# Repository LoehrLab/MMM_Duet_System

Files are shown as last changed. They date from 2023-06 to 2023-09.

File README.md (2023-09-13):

<h1>MMM Duet System</h1>

<h2>Welcome to the MMM Duet System open access build instructions.</h2>

<p>On this site, you will find instructions for how to create your own MMM Duet System. We provide instructions for users who would like to build and use the devices to play musical duets together. We also provide information for researchers and developers who might like to use the MMM Duet System in their research and/or further develop the MMM Duet System. </p>

### [MMM Duet System Hardware](./MMM_Duet_System_Hardware/README.md)
### [MMM Duet System Software](./MMM_Duet_System_Software/README.md)
### [Creating Duets from Commercial Recordings](./Creating_Duets_from_Commercial_Recordings/README.md)

<h3><u>Instructions for users who would like to build and use the devices:</u></h3>
You will need the following software packages.
<ul>
<li>Max 8 or newer </li>
<li>Arduino 1.7 or newer</li>
</ul>

You will also need access to a 3D printer.
<ul><li>
For users who are unfamiliar with 3D printing technology, see https://www.pcmag.com/news/3d-printing-what-you-need-to-know  for an introduction. Note that 3D printing services can be found online or locally. For example, in MMM Duet System’s birthplace, 3D Printing services are available through the public library: https://www.wheatland.sk.ca/services/3D_printing and through a number of 3D printing companies. We used a Prusa i3 MKSS printer with PLA filament for early prototyping and ASA for stronger results in later prototypes. The 3D printing community is very helpful and welcoming if you are having any issues (https://www.reddit.com/r/3Dprinting/, https://forum.prusa3d.com/). Please note that many users’ 3D printing setups show no ventilation, but we strongly advise venting the printer directly outside.</li></ul>

Here are the steps to follow to build your MMM Duet System.
<ol>
<li>Follow the instructions on the MMM Duet System Hardware folder to build your device. </li> 
<li>Follow the instructions on the MMM Duet System Software folder to set up the software. Once this step is complete, you will be able to play duets of various songs that are included in the software package. </li> 
<li>Follow the instructions on the Creating Duets from Commercial Recordings if you’d like to expand the selection of songs to include your personal favourites.</li> 
</ol>

<h3><u>Information for researchers and developers:</u></h3>
<p>To build the MMM Duet System, follow the same instructions as provided for users. Then consult the additional documentation we have provided for developers for further information about how the hardware and software were built and can be modified.</p>
<p>Acknowledgements: Development of the MMM Duet System was supported in part by SHRF, CABHI, and USask Innovation Enterprises.</p>

<p>Please cite this work as follows: Christensen, J., Kauenhofen, S., Loehr, J., Lang, J., Peacock, S., & Nicol, J. (2023). MMM Duet System: New accessible musical technology for people living with dementia. In <i>Proceedings of the 18th International Audio Mostly Conference (Audio Mostly ’23)</i>. Association for Computing Machinery, New York, USA, 7 pages.</p>

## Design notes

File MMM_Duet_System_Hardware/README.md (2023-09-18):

<h1>MMM Duet System Hardware</h1>
<h2><u>Important Files and Sections:</u></h2>

### 1. Shopping list (See section A Below)

### 2. 3D Printing Files (See subfolder Model Files)

These are the files you will need to 3D print the base and handle for each MMM Duet System device.

- Base: 2022_base_model (.f3z, .stl)
  - Component parts:
    - BaseBottom (.3mf, .obj, .stl)
    - BaseTop (.3mf, .obj, .stl)
    - HandleBase (.3mf, .obj, .stl)
- Handle: Crank50mm_solid(.f3z, .stl)
  - Component parts:
    - SolidHandle (.3mf, .obj, .stl)
    - Knob (.3mf, .obj, .stl)

### 3. Arduino Sketch (See subfolder Controller Files)

An Arduino ‘sketch’ is a file that contains the code that runs on an Arduino board (here, the ESP 32). This sketch needs to be loaded onto the Arduino board as detailed in Assembly Step 1.

### 4. Assembly Instructions (See section B Below)

## <u>Overview:</u>

Here are the steps to follow to build the hardware for the MMM Duet System.

1. Purchase items in the Shopping List file.
2. Use a 3D printer to print the components.
3. Put the hardware together by following the steps in the [Assembly Instructions](#b-assembly-instructions).

<h2>A. Shopping List</h2>

This list is for 2 devices

### **Parts**

1. (2) Adafruit Huzzah32 – ESP32 Feather Board (pre-soldered) (https://www.digikey.ca/en/products/detail/adafruit-industries-llc/3591/8119805) This board is slightly more expensive than other ESP32 boards but it was chosen because it comes with a battery charger, JST connection, Wi-Fi and Bluetooth Classic/LE support all on one board. </li>
2. (2) Capacitive Rotary encoders https://www.digikey.ca/en/products/detail/cui-devices/amt103-v/827016
3. (2) 1/4in.(6.35mm)x85mm round metal rods. Note: Rod selection was based partly on availability in our area. For this reason, the holes in the 3D print model are designed to accommodate a 1/4in. (6.35mm) rod. The feel of the rotation can be affected if the gap between the base holes and the rod is too large, so we recommend adjusting the 3D print model to accommodate what is available in your area. The rotary encoders come with a variety of sleeve sizes and can accommodate a broad range of diameters.
4. (2) Protoboards and (4) headers (https://www.amazon.ca/dp/B07CK3RCKS/)
5. (2) Step Up Voltage Module 3.3V to 5V (https://www.amazon.ca/gp/product/B07MTH1R39/)
6. (2) 10K Ohms ±5% and (2) 330K Ohms, ½ Watt, ±5% tolerance, carbon film, resistors
7. (2) 3mm 3.0V-3.4V LED (https://www.amazon.ca/gp/product/B073GRZNRL/)
8. (2)  5 Position MTA 100 Connector Assembly, 22 AWG (https://www.digikey.ca/en/products/detail/te-connectivity-amp-connectors/3-640440-5/698281)
9. (4) Male and (4) Female Spade connectors (optional) (https://www.amazon.ca/gp/product/B08NWXTDN8/)
10. (2) 1000mAh (minimum) Lithium-ion polymer (Lipo) battery (be sure that the polarity of the JST connector matches this https://www.adafruit.com/product/258). There is room for slightly larger batteries, and the model can be modified to accommodate thicker battery packs.
11. (4) M3x8 and (4) M3x12 Hex Screw Bolts (https://www.amazon.ca/gp/product/B0734NVR48/) 
12. (2) M2.6x8 screws (https://www.amazon.ca/Screws-Nickel-Plated-Tapping-Phillips/dp/B0BYNM9522/)
13. (2) M3 Nylon Lock nut (https://www.amazon.ca/gp/product/B07GNH6FVM/)
14. (2) Momentary switches (https://www.amazon.ca/gp/product/B07DS8VSZ1/)

### <b>Supplies</b>

15. 0.6mm Solder (https://www.amazon.ca/gp/product/B071XVPJVX/)  
16. Epoxy (https://www.amazon.ca/Gorilla-Epoxy-85-oz-Clear/dp/B001Z3C3AG/)
17. Filament (depends on printer and desired properties; we used https://us.polymaker.com/products/polylite-asa?variant=39574343221305)  
18. 22AWG Solid Core Wire (https://www.digikey.ca/en/products/detail/adafruit-industries-llc/1311/6198255)
19. Solder Seal Butt Connector (https://www.amazon.ca/NORJIN-Connectors-Waterproof-Electrical-Automotive/dp/B09WQWQQW9/)

### <b>Tools</b>

20. Wire Crimper 
21. Voltage Meter (optional) 
22. Screwdriver that matches bolt/screws 
23. Hot glue gun (optional) 
24. Heat gun 

## B. Assembly Instructions

### **Step 1: Load the Arduino sketch onto the ESP32 board.**

The following instructions explain how to load the Arduino sketch onto the ESP32 Board. We used the Arduino IDE (Integrated Development Environment; see below) due to our familiarity with the software and broad community support.

1. **Install Drivers**
   To load the sketch onto the ESP32 board, you will need to establish a ‘serial connection’ with the board via a ‘COM’ port. To do so, download and install the necessary drivers onto the computer you will use to upload sketch to the board. For a detailed description please visit the manufacturer’s website:
   https://docs.espressif.com/projects/esp-idf/en/latest/esp32/get-started/establish-serial-connection.html

- CP210x Windows/Mac OSX Driver https://www.silabs.com/developers/usb-to-uart-bridge-vcp-drivers

- FTDI Chip VCP Driver https://ftdichip.com/drivers/vcp-drivers/

2. **Set up the Arduino IDE**

- Download and install the Arduino IDE (https://www.arduino.cc/en/software )

- Open the Arduino IDE software, then go to Tools and then Manage Libraries
- Search for and install these libraries:
  - Adafruit BusIO by Adafruit
  - ArduinoOSC by hidekital
- Add the board manager
  - Under File then Preferences, add the following in the text field for Additional Board Manager URLS:
    https://dl.espressif.com/dl/package_esp32_index.json, http://arduino.esp8266.com/stable/package_esp8266com_index.json

3. **‘Flash’ (Arduino’s term for ‘upload’) the sketch onto the board**

- Under Tools, select Board, then ESP32 Arduino, then Adafruit ESP32 Feather
- Plug the USB cable into the board and the computer that you are using to upload the sketch.  
  -Under Tools, select Port, and then select the appropriate COM port. To find the right port: - On PC, open the Device Manager and then expand Ports (COM & LPT). The correct port is listed as Silicon Labs CP210x USB to UART Bridge.

- (Optional) Change the name of the bluetooth controller to avoid confusion with two devices with the same name (e.g., to MMM_Box1).

- Under Sketch, select Upload to upload the sketch to the ESP32 board.

### **Step 2: Wiring**

Below is the wiring schematic. Rather than wire directly to the ESP32 board, we chose to wire to a set of headers soldered to a 30mmx70mm protoboard to prevent damaging the ESP32 board with any soldering mistakes and facilitate reuse of the ESP32 board within the lab (See supplemental information for [soldering instructions](#supplemental-information)).

### Special considerations and recommendations:

- We terminated the ground and positive wires going to the momentary switch with a male spade connector to facilitate connection assembly (optional). Otherwise, the switch can be connected to the protoboard directly.
- The LED is joined to the connecting wires with a solder seal butt connector.
- Connecting the wires to MTA 100 Connector Assembly can be challenging. Rather than acquiring the specialized insertion tool, we used the spanner bit of our screwdriver set.
- We recommend using a volt meter to check conductivity with each connection.

#### **Wiring Diagram**

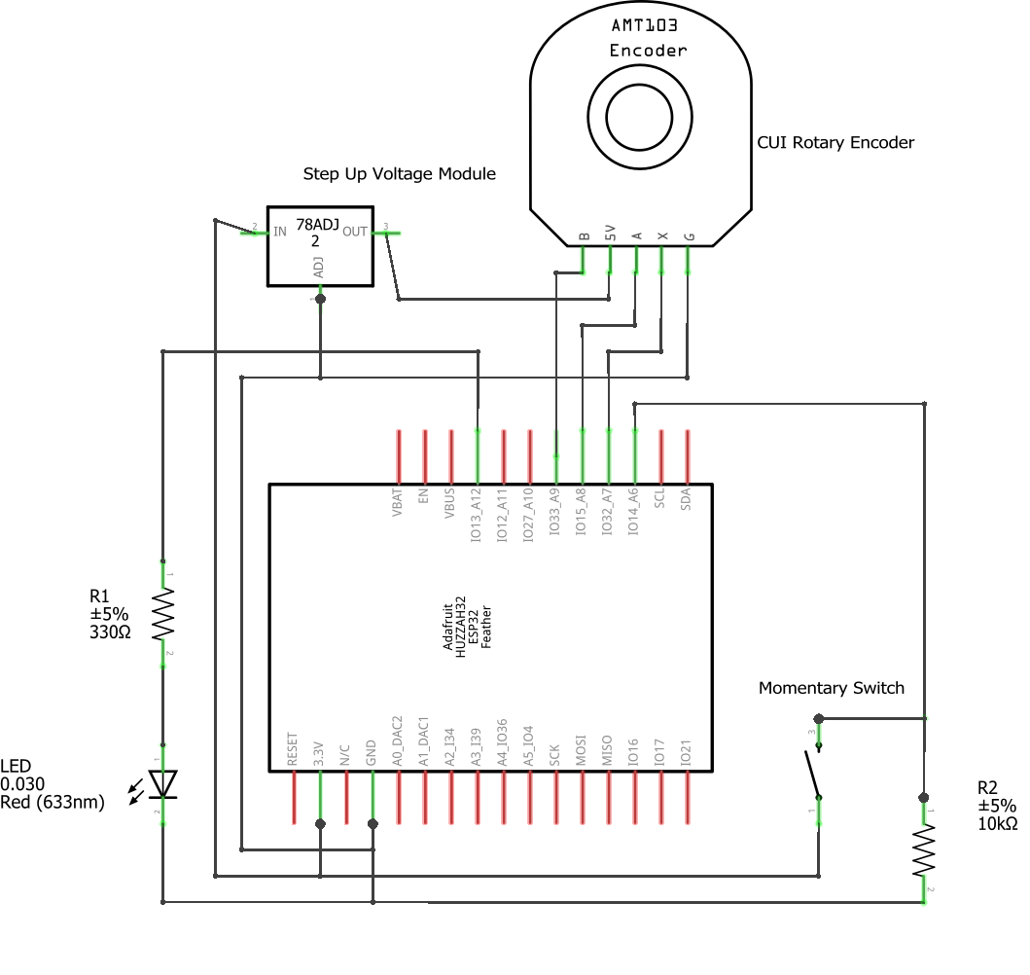
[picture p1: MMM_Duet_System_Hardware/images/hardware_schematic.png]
Wiring Diagram for MMM Duet System.


#### **Breadboard Diagram**

The breadboard diagram below can be used to furhter facilitate conceptualizing of the wiring and testing prior to soldering.
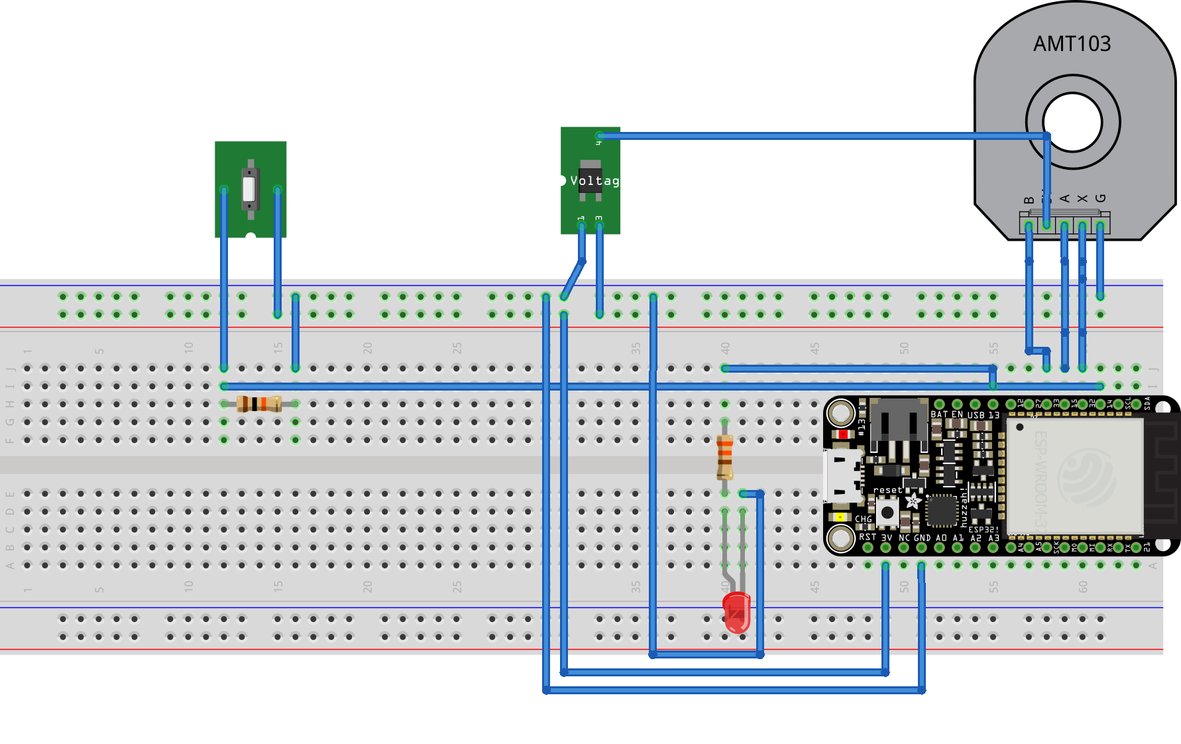
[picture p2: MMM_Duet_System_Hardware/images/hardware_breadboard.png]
Breadboard Diagram for MMM Duet System.


<h3><b>Step 3: Put all the pieces together</b></h3>
<table>
<tr valign="top"><td width="100%">Follow the instructions below to create each MMM Duet System controller.</td></tr>

<tr>
<td width="40%">
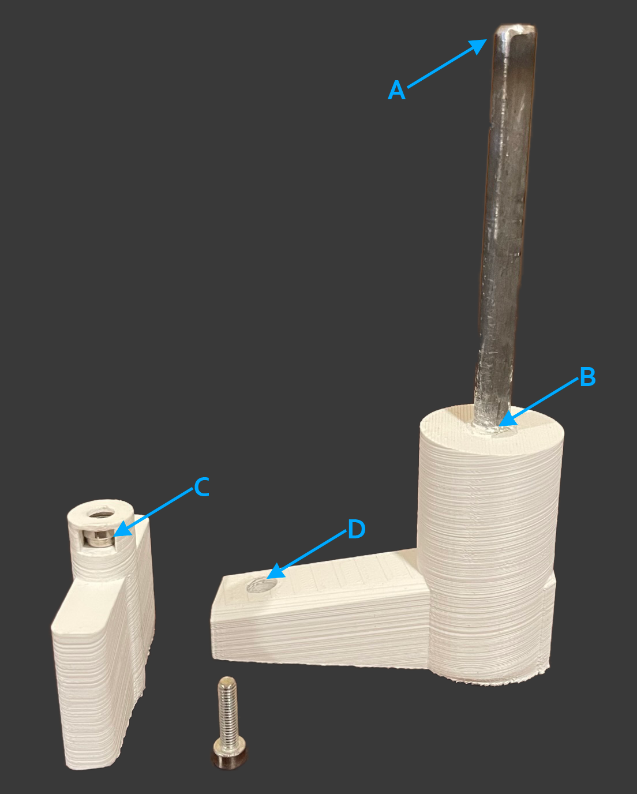
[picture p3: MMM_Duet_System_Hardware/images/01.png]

</td>
<td width="60%">
<ul>
<li>(A) Cut rod to a length of no more than 85mm. Ensure no burs are present to ensure a smooth rotation. </li>
<li>(B) Apply a small amount of epoxy into the hole and quickly set the rod in place. </li>
<li>Let dry before continuing. </li>
<li>(C) Insert the nylon lock nut into the knob such that the hexagon side is towards the circular hole.  </li>
<li>(D) Insert M3x12 screw bolt through handle into knob(C). </li>
</ul>
</td>
</tr>
<tr valign="top">
<td width="40%">
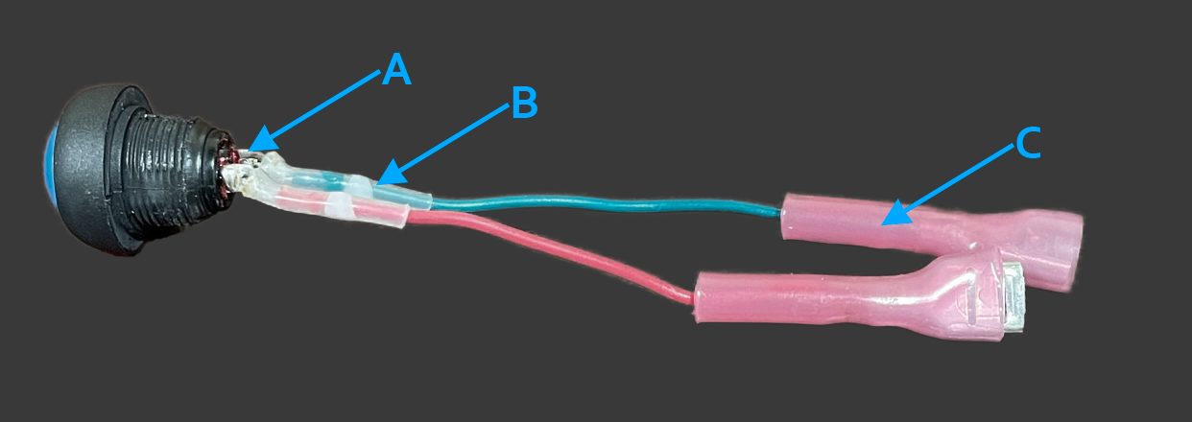
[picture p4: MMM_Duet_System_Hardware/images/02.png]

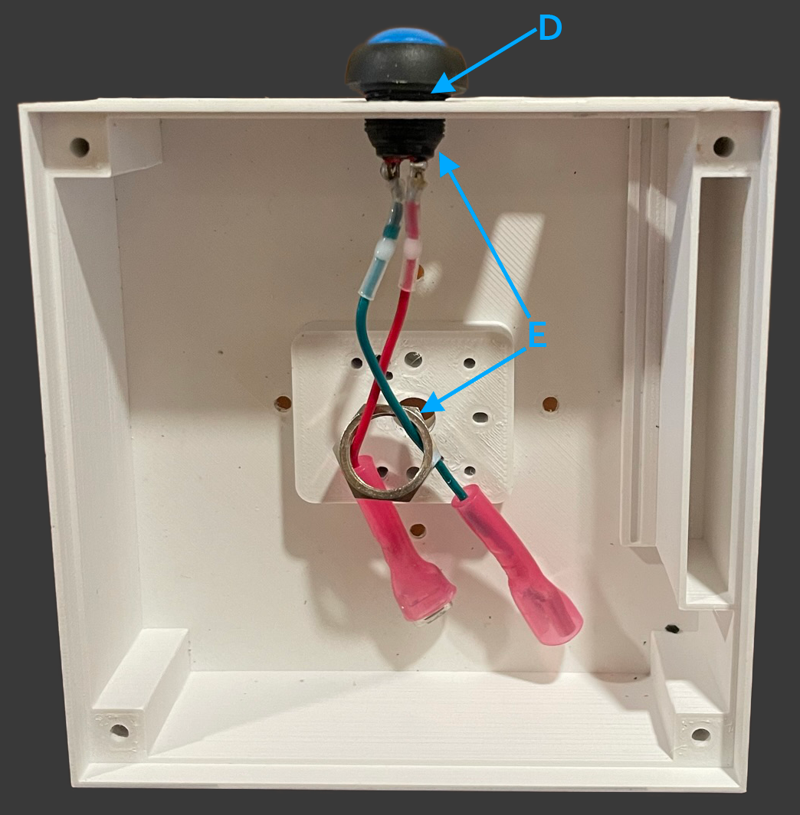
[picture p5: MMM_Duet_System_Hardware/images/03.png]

</td>
<td width="60%">
<ul>
<li>Cut two pieces of wire about 80mm in length; strip both ends.</li>
<li>(A) Hook a wire through each eyelet of the button. </li>
<li>(B) Trim a solder seal butt connector so that the solder is placed where the wire loops onto itself and touches the eyelet.</li> 
<li>Use heat gun to seal butt connector </li>
<li>Repeat for other wire</li>
<li>(C) At the end of the wire, opposite of the button, connect, place a spade connector (female), crimp close and use the heat gun to seal. Optional, you can wire to the protoboard directly, but the wire would need to be cut if any changes would occur in the future. </li>
<li>Repeat for other wire </li>
<li>Remove washer if it is already on the button.</li>
<li>(D) Feed wires through the hole in the base and then through the washer</li>
<li>(E) Tighten washer</li>
</ul>
</td>
</tr>
<tr valign="top">
<td width="40%">
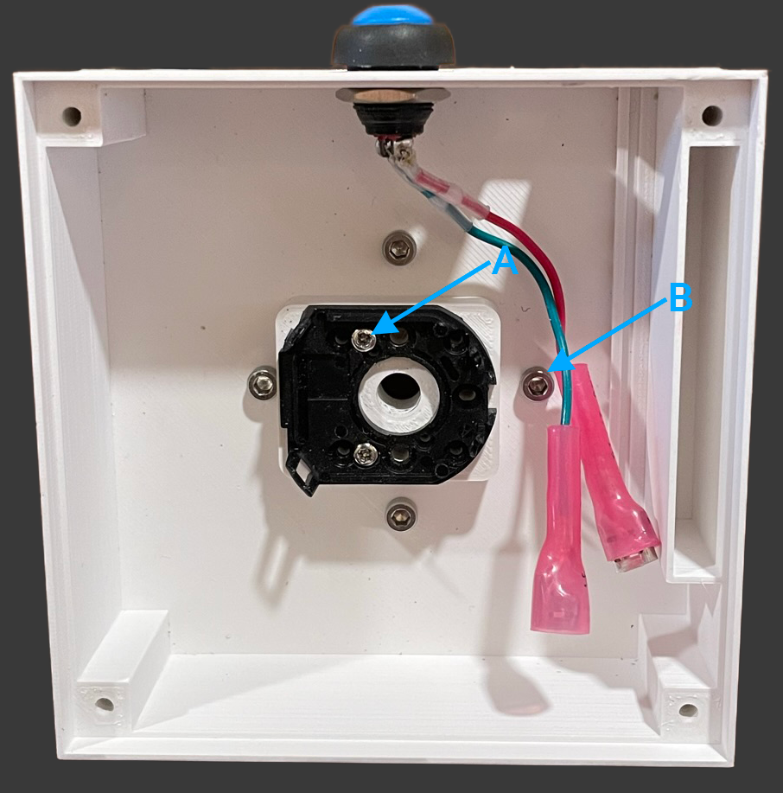
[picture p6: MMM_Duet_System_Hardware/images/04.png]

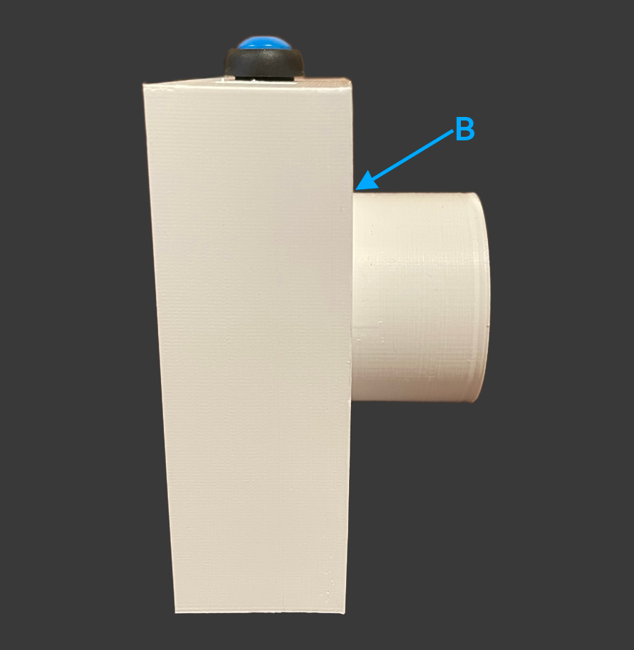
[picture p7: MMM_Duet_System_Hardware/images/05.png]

</td>
<td width="60%">
<ul>
<li>    Align rotary encoder base with the holes in the music box base. </li>
<li>    (A) Insert 2-M2.6x8 screws in two holes that fit snuggly.  </li>
<li>    (B) Align Handle Base (cylinder shape) with the holes in the base. </li> 
<li>    Insert 4-M3x8 screw bolts in the aligned holes </li>
</ul>
</td>
</tr>
<tr valign="top">
<td width="40%">
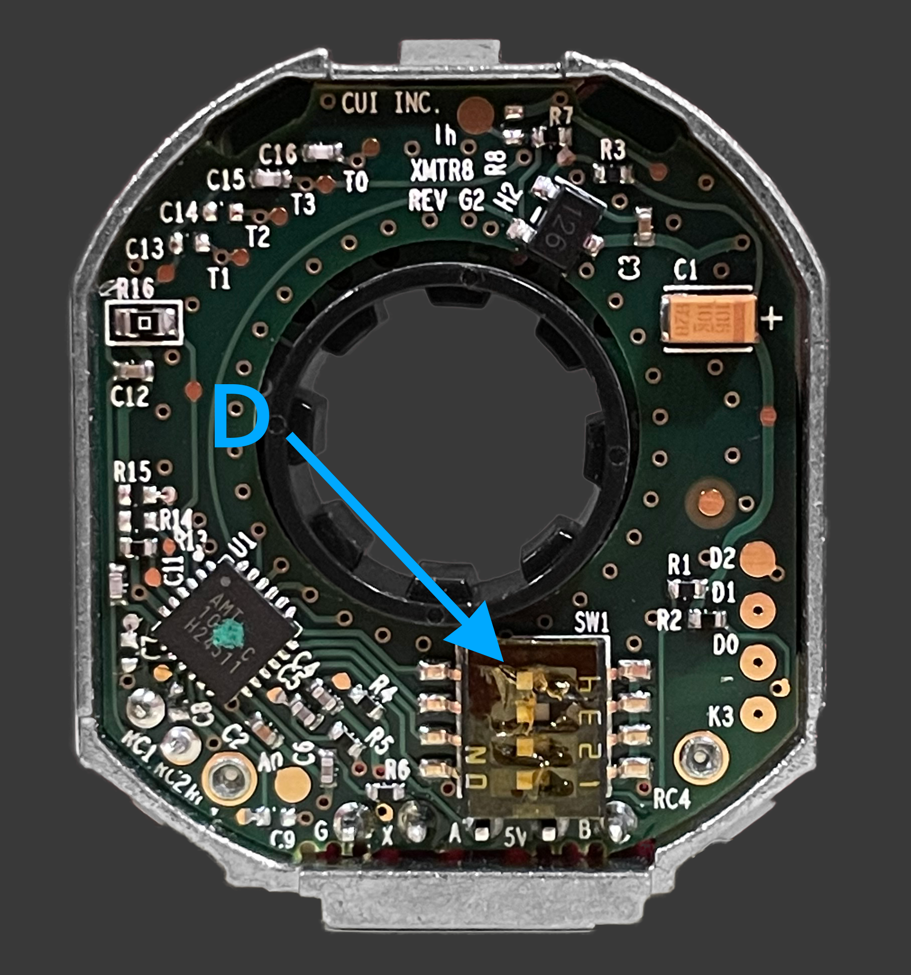
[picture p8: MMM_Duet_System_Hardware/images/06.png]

</td>
<td width="60%">
<ul>
<li>    Adjust the resolution of the encoder to the desired amount. Between 48 and 125 pulses per revolution. See the rotary encoder’s manufacturer’s documentation for more details.  </li>
</ul>
</td>
</tr>
<tr valign="top">
<td width="40%">
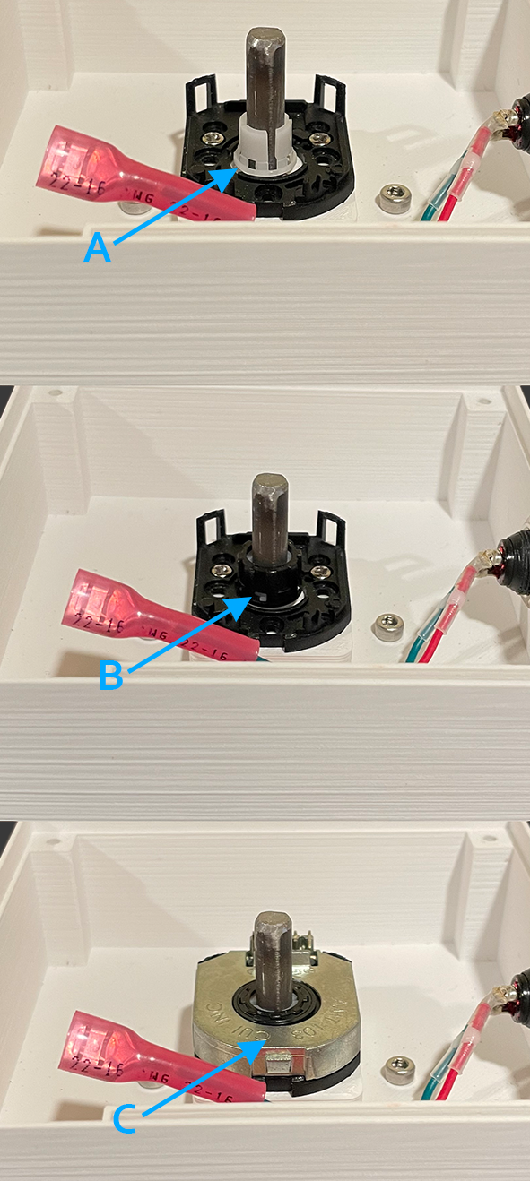
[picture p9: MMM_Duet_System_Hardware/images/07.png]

</td>
<td width="60%">
<ul>
<li>    Push handle as far as possible through the hole at the top of the base. </li>
<li>    (A) Place the coloured sleeve that matches the diameter of the rod approximately 1 mm from the printed model. See https://www.cuidevices.com/product/resource/amt10.pdf for the sleeve sizing guide. </li>
<li>    (B) Place black shaft adapter over the white sleeve. The rod should be difficult to remove at this point. If the sleeve needs to be adjusted remove the shaft adapter and then adjust the sleeve.  </li> 
<li>    (C) Gently clip the encoder into place. The black tabs of the encoder base break easily. </li>
</ul>
</td>
</tr>
<tr valign="top">
<td width="40%">
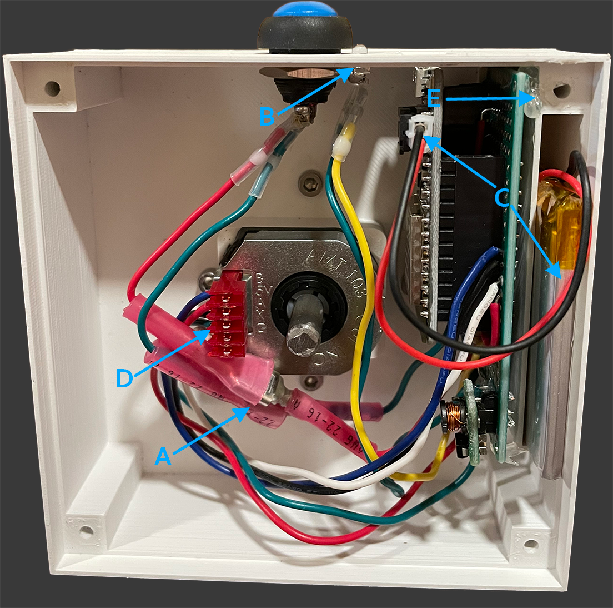
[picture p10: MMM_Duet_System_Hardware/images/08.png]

</td>
<td width="60%">
<ul>
<li>    (A) Connect button spade connectors of the protoboard to those of the ESP32. </li>
<li>    (B) Push LED light snuggly into hole </li>
<li>    (C) Connect battery pack to the ESP32 and place battery in pocket. </li> 
<li>    Seat ESP32 in the headers of the protoboard. </li>
<li>    Place protoboard in slot </li>
<li>    (D) Connect the 5 Position MTA 100 connector to the rotary encoder. </li>
<li>   (Optional) (E) Use hot glue gun to improve stability of protoboard and ease of installation. </li>
</ul>
</td>
</tr>
<tr valign="top">
<td width="40%">
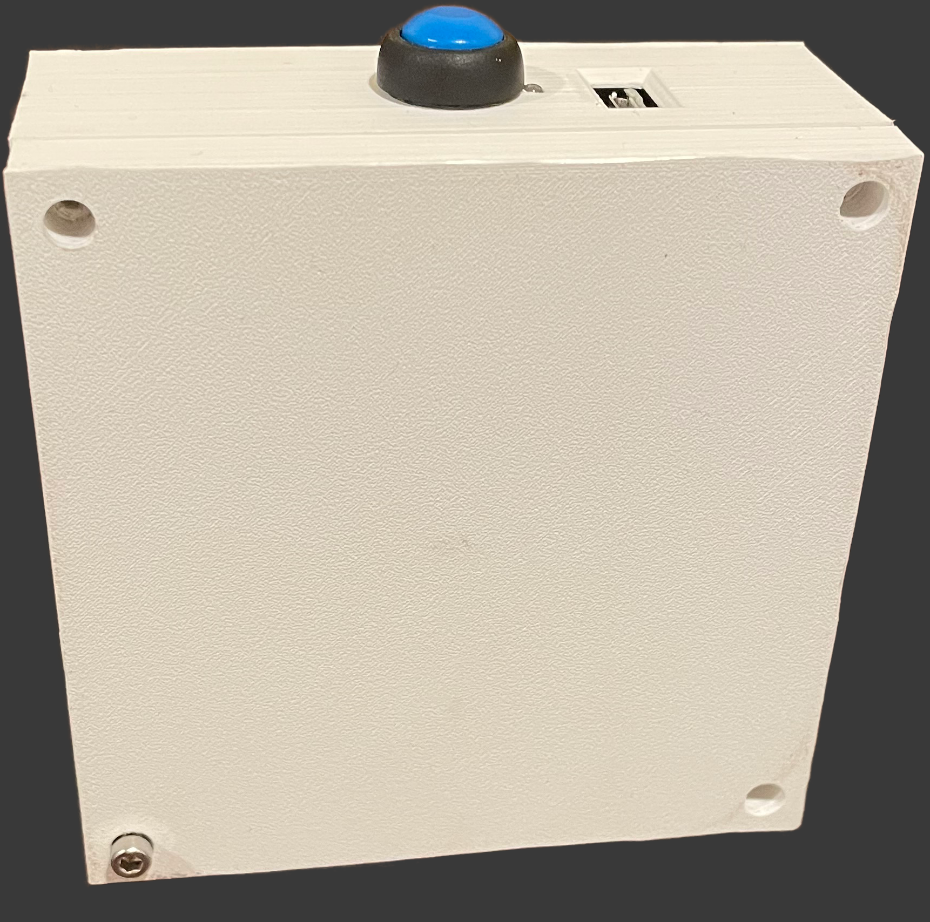
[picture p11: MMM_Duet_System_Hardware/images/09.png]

</td>
<td width="60%">
<ul>
<li>Add bottom panel and screw into place with M3x12 bolt screws. </li>
</ul>
</td>
</tr>
<tr valign="top">
<td width="40%">
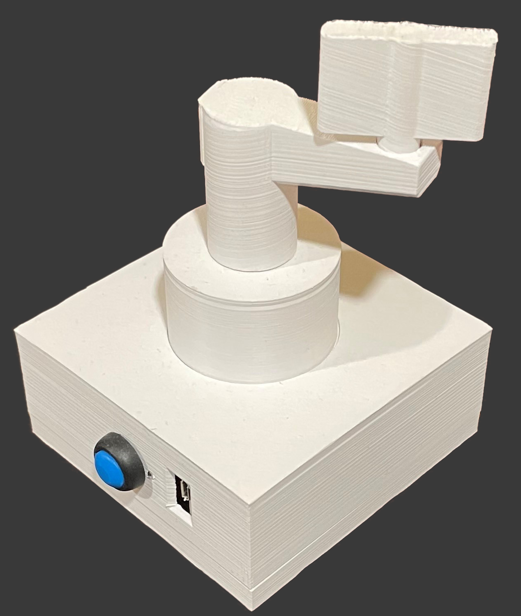
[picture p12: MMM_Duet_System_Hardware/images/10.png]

</td>
<td width="60%">
<ul>
<li>    Enjoy! </li>
</ul>
</td>
</tr>
</table>

## Supplemental Information
<table>
<table><tr valign="top"><h3><b>Soldering instructions</b></h3></tr>
The following Instructions are for putting together ONE device. The images often show two devices being assembled; this is to help aid in understanding by showing multiple angles in one image. Note that there may be other, more efficient ways to assemble the devices; we learned by doing and these are the steps we currently follow to put the devices together.

<tr>
<td width="30%">

1. Place the ESP32 board into a row of headers.
2. Remove excess pins by placing a pliers one pin past the pins you need to keep. In the next step when you snap it, the headers tend to break where it is not solid, which will now be just after the last pin you need.
3. Snap the header.
4. Break off any rough edges.
5. Repeat for the other row of headers.

<td colspan="2">

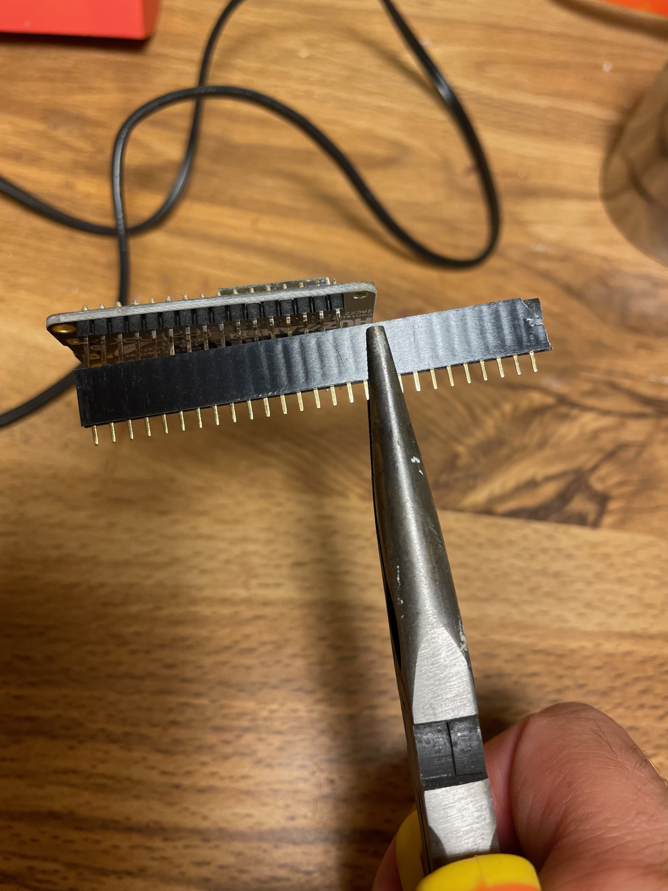
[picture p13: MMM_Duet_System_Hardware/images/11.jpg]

</td>

</tr>
<tr>
<td width="30%">

6. Use the ES32 board to hold the headers in place. Leave one column of holes in the perf board to accommodate wires going to the encoder.
7. Solder at a couple of points to hold the headers in place.
8. Remove the ESP32 board.
9. Solder remaining pins.

<td width="35%">

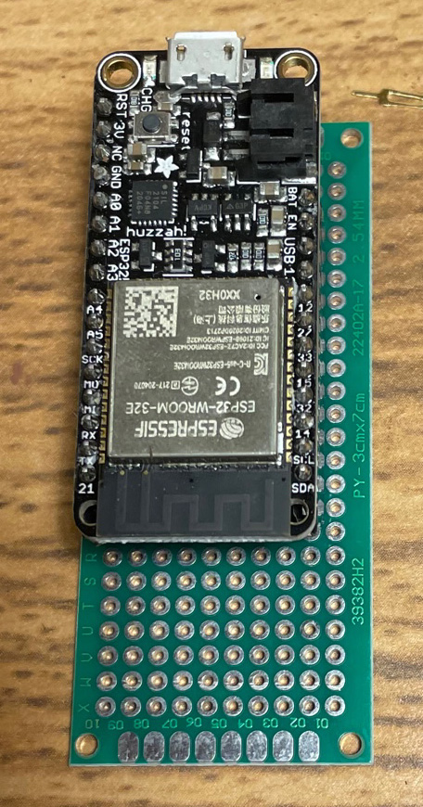
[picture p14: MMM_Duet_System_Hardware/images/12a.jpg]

</td>
<td width="35%">

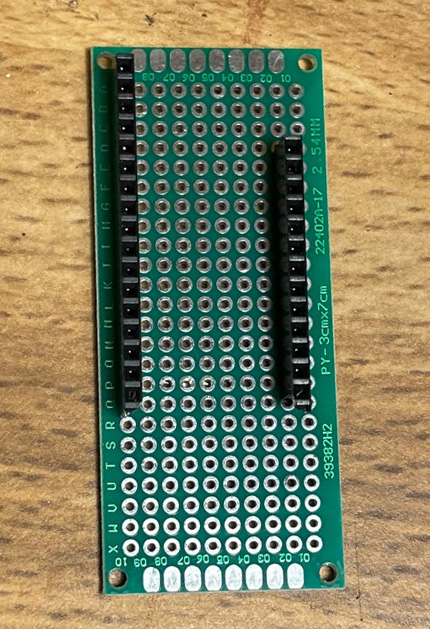
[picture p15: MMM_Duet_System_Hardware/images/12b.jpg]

</td>
</tr>
<tr>
<td width="30%">

10. With the headers securely in place:
11. Cut wires slightly shorter in length than the perf board.
12. Strip the wire ends approximately 1 cm.

<td colspan="2">

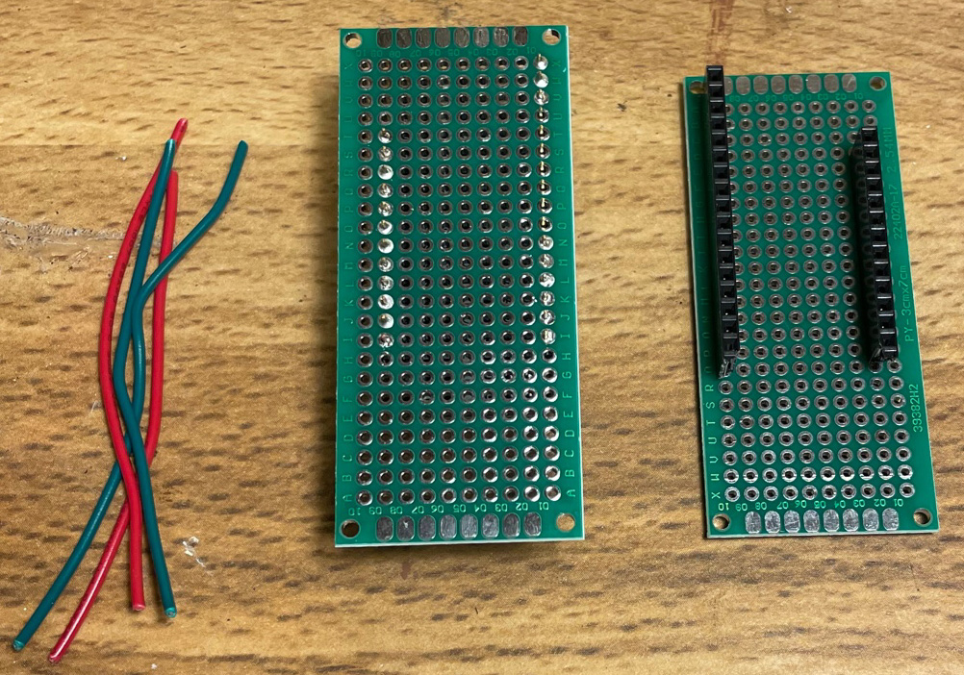
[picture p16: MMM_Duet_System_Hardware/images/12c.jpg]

</td>

</tr>
<tr>
<td width="30%">

13.	Imagine 3 strips (encircled in different colours at the bottom of the board in the image on the right). One for the 3.3V, one for the ground, and one for the 5V. This corresponds to the positions in the Step-up Voltage Module . If the modules do not come with reference material, testing must be done to determine which pin is the higher voltage. In our case the light red corresponds to the 3.3V, the ground is green, and the 5V is dark red. Insert the wire next to the pin of the 3.3V of the ESP32 board (I.e., where the bright red dot is).
14.	Insert the other end on the corresponding strip (I.e., where the bright red dot is on the bottom strip).
15.	Solder the wire at the strip end in place.
16.	Bend the wire over to touch the pin of the header (see image on right). 
17.	Solder the wire to  the pin.
<td width="35%">
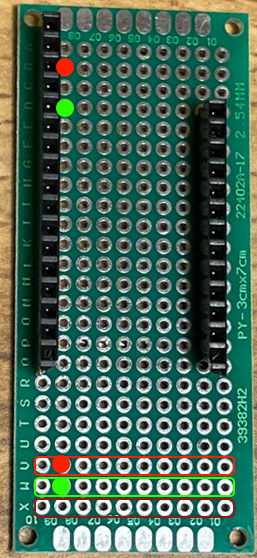
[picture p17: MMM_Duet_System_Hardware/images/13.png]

</td>
<td width="35%">
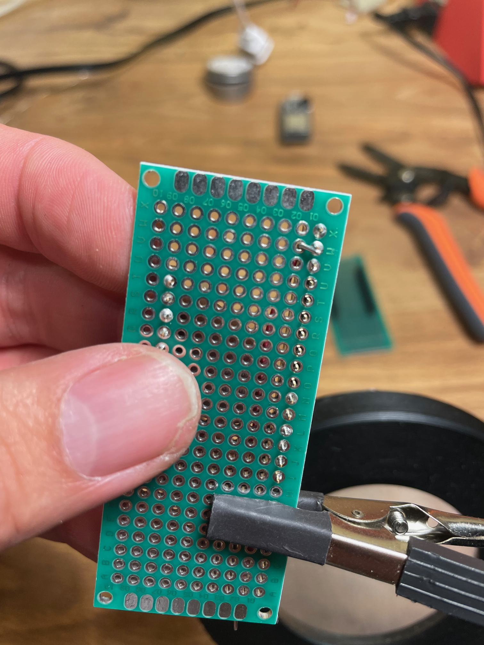
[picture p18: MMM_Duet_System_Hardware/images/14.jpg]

</td>
</tr>
<tr>
<td width="30%">

18.  It is helpful to test the connectivity after each connection in order to avoid having to search for problems later. To do so it is helpful to have some jumper wires inserted into the header as shown on the right. 
<td colspan="2">
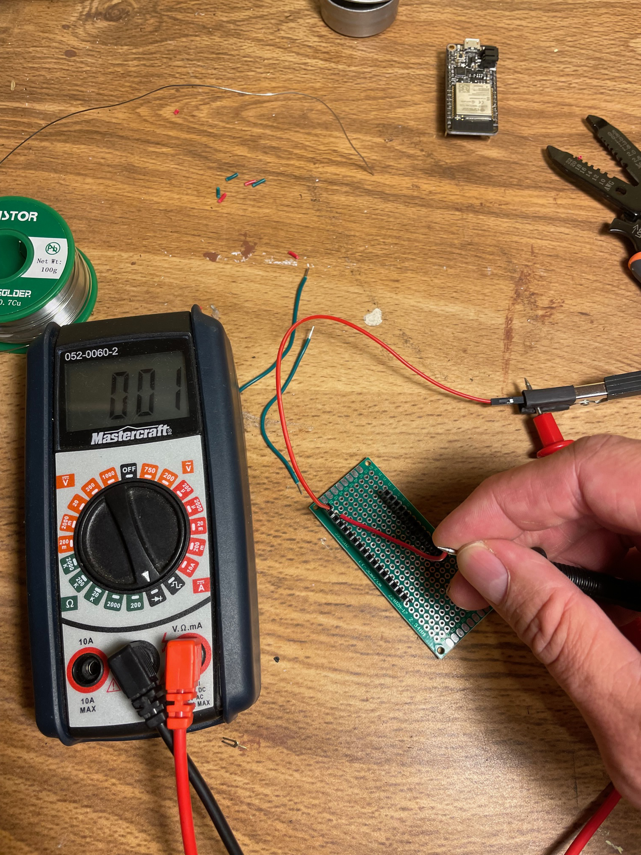
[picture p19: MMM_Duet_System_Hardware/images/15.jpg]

</td>
</tr>

<tr>
<td width="30%">

19.	Cut and strip one end of each of 3 wires about 6 in. (15 cm) in length.
20.	Cut and strip both ends of a wire about 2 in. (5 cm) in length.
21.	Solder the wires, as done previously, adjacent to the A6, A7, A8, & A9 pins. The shorter wire should be adjacent to the A6 pin.
22.	Solder a connection between the wires and their adjacent pins.
23.	Solder a male/male header to connect the Step-up Voltage Module.
<td colspan="2">
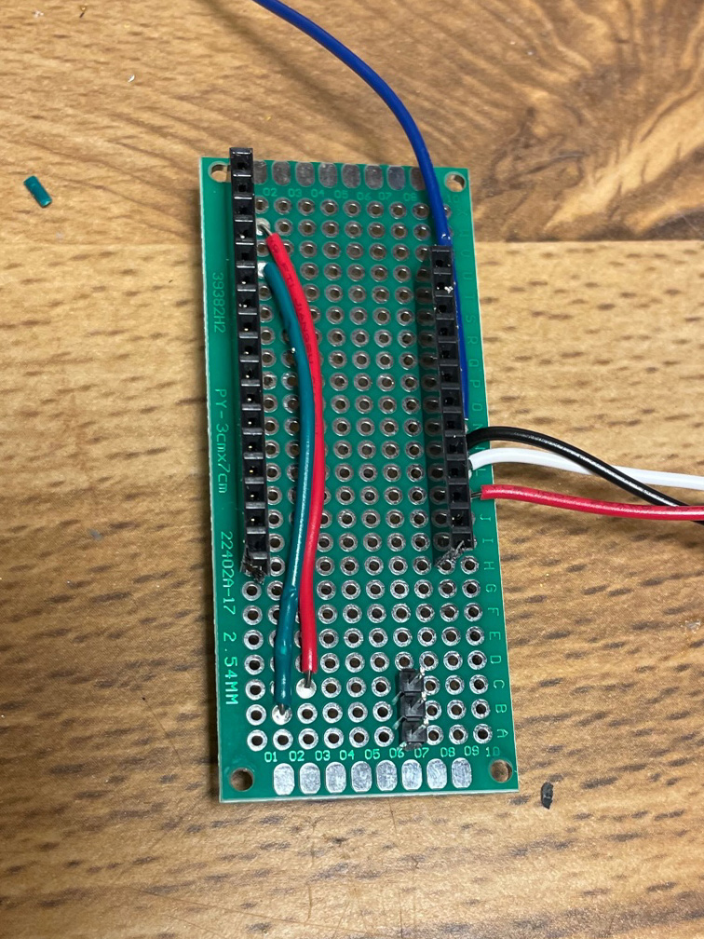
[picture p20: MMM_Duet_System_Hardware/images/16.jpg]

</td>
</tr>

<tr>
<td width="30%">

24.	Place the Step-up Voltage regulator on the header pins. Test to confirm that it is positioned correctly. For the regulators we purchased, the v0 pin was the 5V and the v1 pin was the 3.3V. 
25.	Solder the Step-up Voltage regulator in place.
26.	Solder the wire from the A6 pin somewhere in the space between the rows of headers.
<td colspan="2">
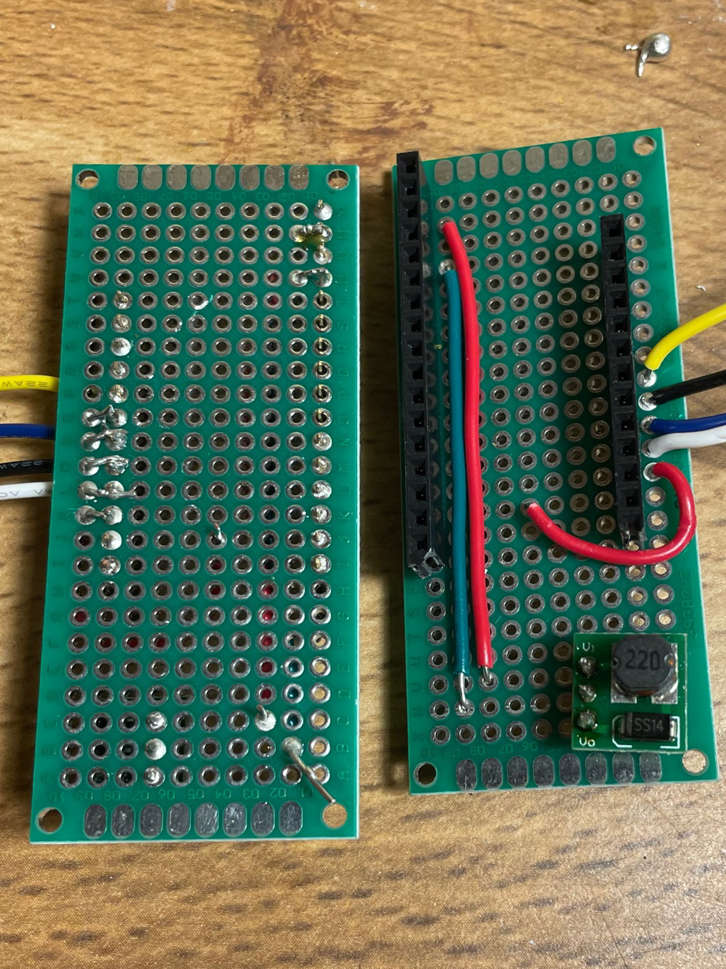
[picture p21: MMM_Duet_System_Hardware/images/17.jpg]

</td>
</tr>

<tr>
<td width="30%">

27.	Solder a 10K Ohm resistor between the wire from the A6 pin to the ground strip shown in step 13.
28.	Solder a connection between the A6 wire and the resistor.
<td colspan="2">
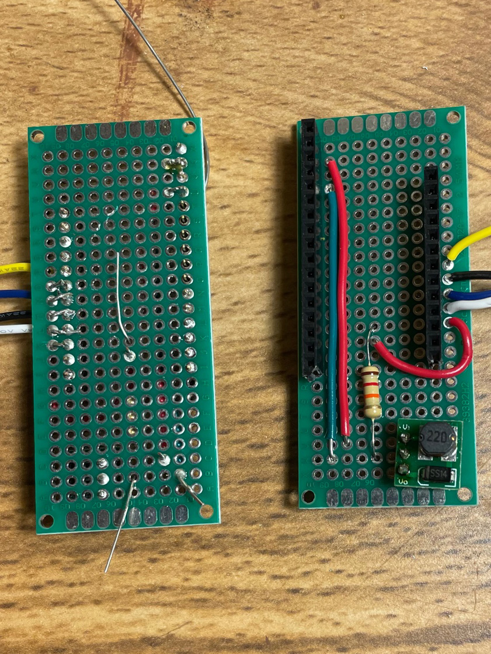
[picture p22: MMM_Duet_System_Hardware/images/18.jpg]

</td>
</tr>

<tr>
<td width="30%">

29.	Cut and strip 2 wires about 4 in. (10 cm) in length (the wires for 2 devices are shown).
30.	Crimp the male spade connectors on the wires.
31.	Use a heat gun to shrink.
32.	Test the connection. If it doesn’t have a satisfactory connection, you can apply a little solder to improve the connection.
<td colspan="2">
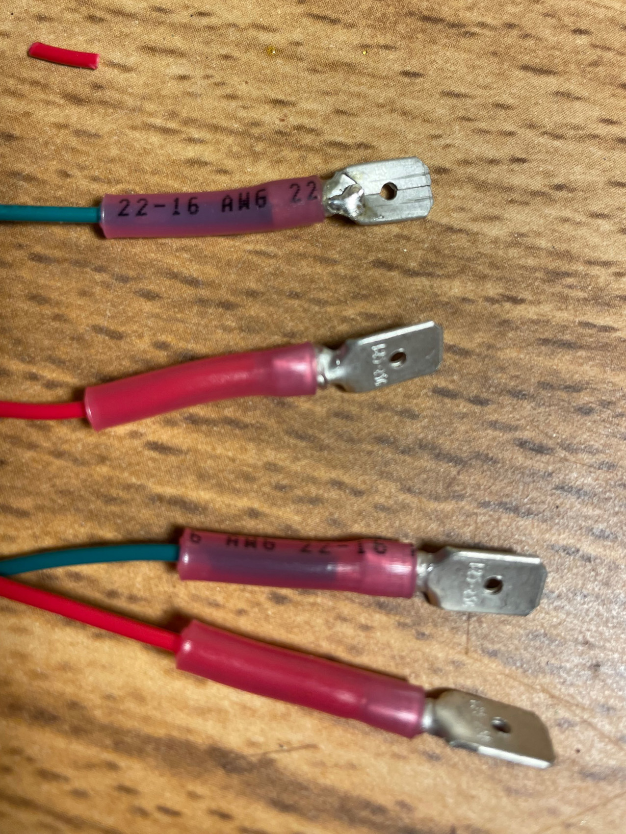
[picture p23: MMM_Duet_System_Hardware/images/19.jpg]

</td>
</tr>

<tr>
<td width="30%">

33.	Solder one wire opposite the 10K Ohm resistor and solder a connection between the two.
34.	Solder one wire to the 3.3V strip shown in Step 13. 
<td colspan="2">
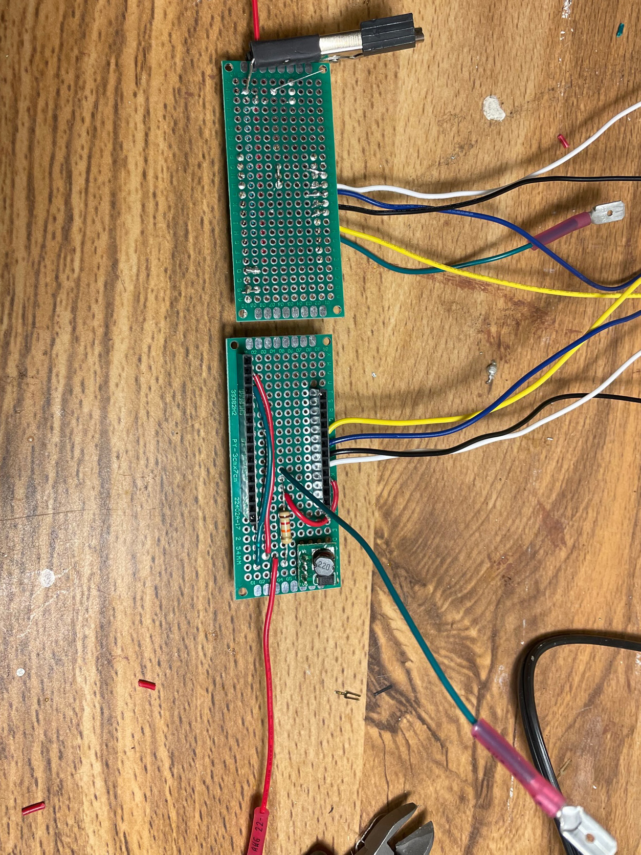
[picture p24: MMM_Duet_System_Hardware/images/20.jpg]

</td>
</tr>

<tr>
<td width="30%">

35.	Insert the 330 Ohm resistor adjacent to the A12 pin. 
36.	Insert the other end into a space between the two rows of headers.
37.	Solder in place.
38.	Solder a connection between the resistor and the A12 pin.
<td colspan="2">

</td>
</tr>

<tr>
<td width="30%">

39.	Cut and strip two wires approximately 4 in. (10 cm) in length.
40.	Cut two solder seal butt connectors so the solder in the middle can seal the connection between the stripped wire and the LED.
41.	Trim the LED of any excess but be sure to keep the longer lead (leg) longer. The longer lead should connect to the resistor and the shorter lead should go to the ground.
42.	Use a heat gun to melt solder and heat wrap.
43.	(Optional) Tape the two wires together just below the LED with electrical tape for strength.

<td width="35%">

</td>
<td width="35%">

</td>
</tr>

<tr>
<td width="30%">

44.	Solder the wire from the longer lead adjacent to the 330 Ohm resistor.
45.	Solder the wire from the shorter lead to the ground strip shown in Step 13.
<td colspan="2">

</td>
</tr>

<tr>
<td width="30%">

46.	Solder a connection between all elements on the 3.3V, and the ground strips respectively. A discarded lead of a resistor or wire can be used to bridge the connection. 
47.	Test each connection on the strip to ensure connectivity. 
<td colspan="2">

</td>
</tr>

<tr>
<td width="30%">

48.	Cut and strip a wire 6 in. (15cm) in length.
49.	Solder the wire to the board on the 5V strip.
50.	Connect it to the Step-up Voltage regulator.
<td colspan="2">

</td>
</tr>

<tr>
<td width="30%">

51.	Cut and strip 2 wires approximately 4 in. (10 cm)
52.	Curl one end and hook it onto the button. 
53.	Trim the solder seal butt connectors similarly to step 38.
54.	Melt the solder with the heat gun.
55.	Repeat for both wires.
<td width="35%">

</td>
<td width="35%">

</td>
</tr>

<tr>
<td width="30%">

56.	Add a female spade connector to the end of each wire opposite of the button.
57.	Crimp.
58.	Use a heat gun to melt the heat wrap.
59.	Test the connection between the button and the spade connector.
<td colspan="2">

</td>
</tr>

<tr>
<td width="30%">

60.	If you do not have the special crimper used for an MTA-100 connector, use a spanner or slotted screwdriver to force the wires into the connector. For a proper connection, the connector needs to slice into the outer casing of the wire.  Note the ends of the wires are not stripped. 
61.	Test the connectivity from the header to the MTA-100 connector. 
62.	Test the 5V connection from anywhere on the strip or at the 5V lead on the Step-up Voltage regulator to the MTA-100 connector. 
<td width="35%">

</td>
<td width="35%">

</td>
</tr>

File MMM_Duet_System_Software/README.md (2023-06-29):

<h1>MMM Duet System Software</h1>

<h2><u>Overview:</u></h2>
Here you will find the software you need to run the MMM Duet System. 
This software runs in Max, version 8 or higher. 
<p>
<u>Instructions for users who would like to build and use the devices</u>: 

Follow the instructions in the “Max patch information for users: Set up and user guide.”</p>

<p>
<u>Information for researchers and developers: </u>: 

Please see explanations for how the patches work in “Max patch information for researchers and developers”.</p>

## A. Max patch information for users: Set up and user guide

 ### **1. Quick start guide**
Once you have the MMM Duet boxes (i.e., the hardware) set up and the MMM Duet software (i.e., the Max patch) downloaded, here is how to quickly start playing the duets with another person. 
1. Ensure the MMM Duet boxes are awake. 
2. Pair MMM Duet boxes to your computer’s Bluetooth.
    - On mac, choose the Bluetooth icon (looks like a ᛒ) in the toolbar at the top right of the screen, and then select Open Bluetooth preferences, and select MMM_Box1 (or whichever name you chose when you loaded the Arduino sketch onto the board). 
    - On PC, 
        1. Go to Bluetooth and other devices settings (can be found in system tray on the taskbar or by search). 
        2. Ensure the device is active (LED is on) 
        3. Click the Add device button. 
        4. Choose Bluetooth Device. 
        5. Select MMM_Box1 (or whichever name you chose when you loaded the Arduino sketch onto the board).
3. Open the MMM Duet software.  
4. Select the appropriate COM ports from Step 2. To see which COM port the device is connected: 
    - On PC,
        1. Go to Bluetooth and other devices settings (can be found in system tray on the taskbar or by search). 
        2. Scroll to the very bottom to More Bluetooth Settings. 
        3. Select the COM Ports tab. 
        4. Find the device name in the list, the desired port is the one listed as the outgoing direction. 

5. Select the song you’d like to play. 
6. Click the ‘Mute/Unmute’ button to unmute the audio. 
7. Click the ‘Play’ button and begin spinning controllers. 
8. Use the ‘Settings’ to adjust spinning speed and smoothing level as needed.  

 ### **2. Guide to the user interface**

Screenshot of presentation mode of MMM Duet software annotated

Once you have the MMM Duet System software up and running, you will see the user interface shown above. See the text below for a detailed description of each element (referenced by a red circled number). 

1. **Sort songs dropdown**: Change how the list of available songs is sorted. Sorting options include alphabetically or by year released. 

2. **Song selection dropdown**: Change which song you will play. Clicking on the white arrow will reveal the list of songs that are currently loaded. If you would like to create your own duets from commercially recorded music, please see the folder titled “Creating Duets from Commercial Recordings” on the MMMDuetSystem Git repository.  

3. **Hide animation toggle**: Show or hide the visual animation of each player’s performance speed. See #10 below for more details. 

4. **Play button**: Toggle this button to begin playing. 

5. **Mute button**: Toggle this button to mute/unmute sound. 

6. **Help button**: Press this button to open a help document for guidance. 

7. **Port dropdown**: Select the corresponding ports for each controller (see Bluetooth Port Selection & Parsing for greater detail). 

8. **Spinning speed dropdown**: Select spinning speed level based on device/player performance (see Device Speed Calibration for greater detail). 

9. **Smoothing level dropdown**: Select smoothing level based on player performance (see Smoothing Calibration for greater detail). 

10. **Vehicle Movement toggle**: Toggle this button to switch the vehicles in the visualization between ‘movement based on player rotational speed’ mode and ‘movement based on player’s rotational consistency’ mode. 

## B. Max patch information for researchers and developers
 ### **1. General information about the patch** 
Below is a diagram that shows all the components of the MMMDuet System. Please note that the component labeled “Game Controller Script” refers to the Arduino code that is loaded onto each Arduino. This component is described on the MMM Duet System Hardware page. All other components are included in the Max patch. The Max patch is organized by components with each component being comprised of Max objects, and 0 or more Max subpatches.  Some of the subpatches have subpatches as well. The component diagram below shows the overall organization of the MMM_Patch, the main patch. The text between components (e.g., “< songpic”) indicates variables being passed from one component to another with the bracket indicating the direction of transmission. 

Component Diagram of the system
 ### **2. Components** 
 For simplicity, we have grouped the components into three main overarching groups: Input- and Output-related components; Music Selection components, Duet Facilitation components; and Visual components.  

## A. INPUT- and OUTPUT-RELATED COMPONENTS: 
The following components deal with input to the Max patch. 
### <u>Game Controller (Arduino) Script </u>

The MMM Patch currently takes the serial output from the microcontroller as its input, but it can take any serial ASCII information as its input as long as it is unsigned (not negative). As the largest bottleneck in the system is between the microcontroller and computer, the information is currently being sent as 2 Byte unsigned integers, but Max can also easily handle 4 Byte unsigned long integers. Each datapoint can either be separated by a space (ascii 32), by a line return (ascii 10), or by a full carriage return (ascii 13 and 10). Some Bluetooth handle these dividers differently, so each of them have been tried to achieve the best latency possible. Different baud rates should also be tested to ensure reduced latency. 

### <u>Session Recording </u>

Currently, whenever the recording function is enabled and a song is played, 4 textfiles are created. One contains the raw data coming from the musicbox1, one the raw data of musicbox 2, another containing the data of musicbox 1 after being smoothed by the smoothing functions, another containing the smoothed data of musicbox 2 (that matches the sounding result of the actions). The raw textfiles are named after the time of the performance, their musicbox # (the left musicbox is musicbox1 and the right musicbox is musicbox2), whether they were in solo or duet mode, the degree of smoothing assistance # during the song, the spinning speed # of that musicbox, and the song number. The smoothed textfiles are the same except they start with the word smooth. In addition to the timing information embedded within each file is each stop-point that has occurred in either partner’s part, and each time that either part has been moved to be realigned the other part.  

### <u>Bluetooth Port Selection & Parsing </u>
Screenshot of Bluetooth Port Selection & Parsing subpatch 

## B. MUSIC SELECTION COMPONENTS:
The following component helps people to add and select the music of their choice.  

This subpatch uses text files that lists a) the accompaniment wav file of the song b) the melody wav file of the song, c) name of open source image of singer, tempo of song, and year of recording. 

For people who want to add their own songs to the system, please go see [Creating Duets from Commercial Recordings](https://github.com/LoehrLab/MMM_Duet_System/tree/main/Creating%20Duets%20from%20Commercial%20Recordings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). 
## C. DUET FACILITATION COMPONENTS:
The following components help players synchronize the duets together. Each component can be set to a different level to adjust duet playing difficulty (making it easier or harder to stay in synchrony with the partner). These components were implemented to allow for satisfying duet performance across a wide variety of individual differences in performance ability (e.g., different musical skills, motor constraints, etc.).  
### <u>Device Speed Calibration (MMM_patch section E)</u>
The subpatch SpinSpeedCalibration serves two functions. 

1. You can manually adjust playback to account for players’ preferred and actual spinning speed Since we want to know the spinning speed of the musicboxes, we measure the time it takes to move from one location on the rotary encoder of the musicbox to the next. Then we take a prechosen numerator to be divided by this length of time to find out the spinning speed. This subpatch uses a range of numerators to match a spinning speed to the intended spinning speed of a player. The larger the numerator used, the slower the spinning speed required to match the original audiofile speed. The spinning speed levels shown on the screen range from 0 to 10, with 0 corresponding to the slowest spinning speed, and 10 corresponding to the fastest. The component uses these levels to choose a numerator to divide the input time from the music boxes.   The ‘normal’ preset numerator is 40, but numerators range from 17 – 190 (17, 20, 25, 30, 35, 40, 60, 80, 110, 150, 190). Also, the greater the numerator (the slower the spinning speed), the greater the need for smoothing.  

2. Adjust playback to account for the original tempo of the song. This subpatch also includes a function that takes the average tempo of the song and adjusts the spinning speed slightly to match the tempo (seen as the speechbubble input ‘Tempo’), increasing the spinning speed required for faster songs, and decreasing the spinning speed required for slower songs. 

Screenshot of spin speed calibration subpatch

### <u>Speed Correction (Smoothing Lvl 1) - (MMM_Patch section F)</u>

A large role of the subpatch Smoov is to protect against dividing by zero. This subpatch uses a feedback loop to diminish the distance of outlier datapoints from the mean. In essence, it keeps a running mean of the last 100 datapoints in order to bring the newest datapoint closer to the running mean. This subpatch was especially important in the early versions of the patch where we were inputting rotational information into the MMM Patch. As we improve the regularity and latency of the input to the MMM Patch this subpatch will become less important, and its aggressiveness should be adjusted accordingly. 

Screenshot of speed correction

### <u>Smoothing Correction (MMM_Patch Section H)</u>

The purpose of the SmoothingFunction subpatch is to smooth the speed of their musical output relative to the player’s spinning speed. With no smoothing, the speed of the musical output varies with the speed of the player’s spinning. With high levels of smoothing, the speed of the musical output remains stable even if the player’s spinning speed is variable. 

SmoothingFunction is based on variations of the mathematical formula y = (x - 1)n/m + 1. This pushes players towards the correct speed (1,1) in order to help them match the original audiofile speed. There is also a limiter at the top, to stop the function from getting out of control when it is spun too fast. Here is an example of a smoothing function for smoothing level 0. 
Screenshot of smoothing correction

Different levels of smoothing vary the m and n of the above function. Here is an image of the resultant curves (black, level , has the least amount of smoothing while red, level 7, has the most) : 

Smoothing function curves

### <u>Automatic realignment (MMM_Patch Section A, component Auto-adjust):</u>

The purpose of the Auto-adjust subpatch is to allow for automatic realignment of the two players’ parts if they drift so far apart that they are unlikely to be able to realign with each other simply by adjusting their own spinning speeds. Feedback from early users indicated that moving the accompaniment part to the melody part is less noticeable, so this is always done. Currently, whenever the participants get off by more than 1.5 seconds (66150 samples at 44100) the parts are automatically realigned. The parts are also realigned whenever the parts get off by over 1 second (44100 samples) for 1 second, and off by over .5 seconds (22050 samples) for over 2 seconds (It may appear that the < sign is reversed for these 2 in the patch but they are correct as clocker restarts every time it is banged). The musicbox that has the melody part is known through the r lr function. 
Screenshot of auto-adjust

In terms of technical implementation of this function, the current sample of the audiofile can be known by tracking the sig~ function, (this tracking is shown in section I. Player switching), summing the samples that have occurred in the signal accumulator, and taking snapshots of this running total. These snapshots are then shown in message boxes (NB: mbox 1 snapshot is shown on the right of the patch while mbox 2 is shown on the left – this has been done as the value in these message boxes become the new value for the other part when realignment is done). E.g. When a realignment request is made to move mbox1 to mbox2, the current sample of mbox2 is fed back into the signal accumulator (**+=~**) of mbox1.  

### <u>Bluetooth Code Processing (MMM_Patch Section J):</u>

As the patch doesn’t really know the spinning speed of the musicboxes, it doesn’t really know when players have stopped mid-song. All the MMM patch has is the latest information given to it, which is the last duration recorded between the last 2 points it has seen from the musicbox (which it estimates the current speed from – see spinning speed above). Therefore, an audio-off has been added to allow the audiofile to stop playing when it hasn’t received any new input information. The component takes the smoothingRaw value and outputs it as audio-off. When the player is spinning, they are the same. After 320 msec of inactivity, the controller sends a the ASCII characters “/D”. After 640 msec, the controller sends out “/E”. After another 320 msec, at 960 msec, the controller sends out “/F”. The MMM Patch registers this as the ASCII numbers 68, 69, 70 respectively.  When 68, is received, the last smoothingRaw value transitions to 0.3 over 330 msec becoming vidrate. When 69 is received, it transitions from 0.3 to 0. When 70 is received, nothing happens, but this functions to stop the repeated triggering of the transition from 0.3 to 0. 

Screenshot of bluetooth code processing

### <u>Signal Processing Component (MMM_Patch Section K):</u>

It takes all of the inputs from the components described above (e.g., speed calibration, smoothing correction, song selection, etc.) and uses that information to add the song to the player and adjust the speed and amplitude of the audio file in the music player. 

One aspect of the Signal Processing component that hasn’t been described elsewhere is a function that makes continual slight adjustments to the amplitude of the audio output tied to speed of the spinning, that is, the faster the spinning, the louder the output”. This follows the idea of a transfer of energy from speed into volume, so that people can still feel that their quick actions are being responded to, even if it is not reflected in large quick changes in speed. This is implemented in the Signal Processing component. 

## C. VISUAL COMPONENTS:
The following components allow the users to display, or not, visual feedback about how well their performances are aligning together. 

### <u>Visualizations (MMM_Patch Section B):</u>

Early users sometimes over-focused on the visual performance feedback to ensure they were doing the task ‘correctly’, and found that this interfered with ability to enjoy performing the duets with their partner. This subpatch offers users the option was added to hide the dynamic visual feedback from the screen and instead display a static image. This is either activated through a toggle or through a keyboard shortcut. The static image is determined by the file specified in the Song Library files (see Song Library section below). 

Screenshot of visualization toggle

### <u>Auto Solo or Duet mode (p practice): </u>

The dynamic visual feedback works either as a comparison between a player and the original song speed (solo mode) or as a comparison between a player and their partner. This function borrows from the auto-stop function to know whether both players are playing or not. The default state is duet mode, but it moves the visual feedback into solo mode when one of the players has not been heard from in over 660 msec. Similar to the auto-stop function, duet mode is reactivated immediately as soon as there is feedback that both players are playing at the same time. 

Screenshot of auto solo or duet mode

### <u>Visualization: </u>

The visualization in the system is governed by the VideoControl subpatch. In the E. Vehicle Position & Attributes subcomponent, the rotational speed of the player, along with the rotation1 and rotation2 variables, is converted into a percentage of the 40 msec, the time limit set in the controller script. This percentage is then subtracted from 1 to obtain the rotation ratio, where the maximum speed is 1 and the minimum speed is 0. 

The rotation ratios from both controllers are combined and sent to the G. Road Position and Rotation subcomponent as the jointRotation variable. Here, a rolling average of the most recent 10 jointRotation values is computed, which is then translated into a rotation of the road and background. 

The individual performance of the player, as represented by the rotation ratios, is evaluated by the PlayerStatistics subpatches. Two performance indicators are calculated using different methods: 

- Direct Rotation Method: This method computes a rolling mean, variance, and standard deviation of the most recent 50 rotation ratios. The rolling mean is used to determine the position of the player, which is adjusted to the left side of the visualization when no rotation is recorded. 

- Cadence Method: This method builds on the Direct Rotation Method by maintaining a resting mean value that is updated when the current rolling mean is outside of 1 standard deviation from the previous resting mean. The current rolling mean is then compared to the resting mean, and the vehicle moves forward if the player is slightly faster than the resting mean, while it stays centered if the player rotates at a consistent speed or not at all.

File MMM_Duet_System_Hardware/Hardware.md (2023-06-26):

<h1>MMM Duet System Hardware</h1>

<h2><u>Overview:</u></h2>
Here are the steps to follow to build the hardware for the MMM Duet System.
<ol>
<li>Purchase items in the Shopping List file.</li>
<li>Use a 3D printer to print the components.</li>
<li>Put the hardware together by following the steps in the Assembly Instructions file.</li>
</ol>

<h2>A. Shopping List</h2>

This list is for 2 devices
<h3><b>Parts</b><h3>

1. (2) Adafruit Huzzah32 – ESP32 Feather Board (pre-soldered) (https://www.digikey.ca/en/products/detail/adafruit-industries-llc/3591/8119805) This board is slightly more expensive than other ESP32 boards but it was chosen because it comes with a battery charger, JST connection, Wi-Fi and Bluetooth Classic/LE support all on one board. </li>

2. (2) Capacitive Rotary encoders https://www.digikey.ca/en/products/detail/cui-devices/amt103-v/827016

3. (2) 1/4in.(6.35mm)x85mm round metal rods. Note: Rod selection was based partly on availability in our area. For this reason, the holes in the 3D print model are designed to accommodate a 1/4in. (6.35mm) rod. The feel of the rotation can be affected if the gap between the base holes and the rod is too large, so we recommend adjusting the 3D print model to accommodate what is available in your area. The rotary encoders come with a variety of sleeve sizes and can accommodate a broad range of diameters.

4. (2) Protoboards and (4) headers (https://www.amazon.ca/dp/B07CK3RCKS/)

5. (2) Step Up Voltage Module 3.3V to 5V (https://www.amazon.ca/gp/product/B07MTH1R39/)

6. (2) 10K Ohms ±5% and (2) 330K Ohms, ½ Watt, ±5% tolerance, carbon film, resistors

7. (2) 3mm 3.0V-3.4V LED (https://www.amazon.ca/gp/product/B073GRZNRL/)

8. (2)  5 Position MTA 100 Connector Assembly, 22 AWG (https://www.digikey.ca/en/products/detail/te-connectivity-amp-connectors/3-640440-5/698281)

9. (4) Male and (4) Female Spade connectors (optional) (https://www.amazon.ca/gp/product/B08NWXTDN8/)

10. (2) 1000mAh (minimum) Lithium-ion polymer (Lipo) battery (be sure that the polarity of the JST connector matches this https://www.adafruit.com/product/258). There is room for slightly larger batteries, and the model can be modified to accommodate thicker battery packs.

11. (4) M3x8 and (4) M3x12 Hex Screw Bolts (https://www.amazon.ca/gp/product/B0734NVR48/) 

12. (2) M2.6x8 screws (https://www.amazon.ca/Screws-Nickel-Plated-Tapping-Phillips/dp/B0BYNM9522/)

13. (2) M3 Nylon Lock nut (https://www.amazon.ca/gp/product/B07GNH6FVM/)

14. (2) Momentary switches (https://www.amazon.ca/gp/product/B07DS8VSZ1/)

<h3><b>Supplies</b><h3>

15. 0.6mm Solder (https://www.amazon.ca/gp/product/B071XVPJVX/)  

16. Epoxy (https://www.amazon.ca/Gorilla-Epoxy-85-oz-Clear/dp/B001Z3C3AG/) 
</li> 

17. Filament (depends on printer and desired properties; we used https://us.polymaker.com/products/polylite-asa?variant=39574343221305)  
18. 22AWG Solid Core Wire (https://www.digikey.ca/en/products/detail/adafruit-industries-llc/1311/6198255)
19. Solder Seal Butt Connector (https://www.amazon.ca/NORJIN-Connectors-Waterproof-Electrical-Automotive/dp/B09WQWQQW9/)

<h3><b>Tools</b><h3>

15. Wire Crimper 
16. Voltage Meter (optional) 
17. Screwdriver that matches bolt/screws 
18. Hot glue gun (optional) 
19. Heat gun 

<h2>B. Assembly Instructions</h2>
<h3><b>Step 1: Load the Arduino sketch onto the ESP32 board. </b><h3>
The following instructions explain how to load the Arduino sketch onto the ESP32 Board. We used the Arduino IDE (Integrated Development Environment; see below) due to our familiarity with the software and broad community support.  

1. **Install Drivers**
To load the sketch onto the ESP32 board, you will need to establish a ‘serial connection’ with the board via a ‘COM’ port. To do so, download and install the necessary drivers onto the computer you will use to upload sketch to the board. For a detailed description please visit the manufacturer’s website: 
https://docs.espressif.com/projects/esp-idf/en/latest/esp32/get-started/establish-serial-connection.html 

- CP210x Windows/Mac OSX Driver https://www.silabs.com/developers/usb-to-uart-bridge-vcp-drivers 

- FTDI Chip VCP Driver https://ftdichip.com/drivers/vcp-drivers/ 

2. **Set up the Arduino IDE**

- Download and install the Arduino IDE (https://www.arduino.cc/en/software ) 

- Open the Arduino IDE software, then go to Tools and then Manage Libraries 
- Search for and install these libraries: 
    - Adafruit BusIO by Adafruit 
    - ArduinoOSC by hidekital 
- Add the board manager 
    - Under File then Preferences, add the following in the text field for Additional Board Manager URLS:
    https://dl.espressif.com/dl/package_esp32_index.json, http://arduino.esp8266.com/stable/package_esp8266com_index.json 

3. **‘Flash’ (Arduino’s term for ‘upload’) the sketch onto the board**
- Under Tools, select Board, then ESP32 Arduino, then Adafruit ESP32 Feather 
- Plug the USB cable into the board and the computer that you are using to upload the sketch.  
-Under Tools, select Port, and then select the appropriate COM port. To find the right port: 
    - On PC, open the Device Manager and then expand Ports (COM & LPT). The correct port is listed as Silicon Labs CP210x USB to UART Bridge. 

- (Optional) Change the name of the bluetooth controller to avoid confusion with two devices with the same name (e.g., to MMM_Box1). 

- Under Sketch, select Upload to upload the sketch to the ESP32 board.  

<h3><b>Step 2: Wiring </b><h3>

Below is the wiring schematic. Rather than wire directly to the ESP32 board, we chose to wire to a set of headers soldered to a 30mmx70mm protoboard to prevent damaging the ESP32 board with any soldering mistakes and facilitate reuse of the ESP32 board within the lab.

### Special considerations and recommendations:
* We terminated the ground and positive wires going to the momentary switch with a male spade connector to facilitate connection assembly (optional). Otherwise, the switch can be connected to the protoboard directly. 
* The LED is joined to the connecting wires with a solder seal butt connector. 
* Connecting the wires to MTA 100 Connector Assembly can be challenging. Rather than acquiring the specialized insertion tool, we used the spanner bit of our screwdriver set.
* We recommend using a volt meter to check conductivity with each connection. 

#### **Wiring Diagram**
Wiring Diagram for MMM Duet System.

#### **Breadboard Diagram**
The breadboard diagram below can be used to furhter facilitate conceptualizing of the wiring and testing prior to soldering. 
Breadboard Diagram for MMM Duet System. 

<h3><b>Step 3: Put all the pieces together</b><h3>
Follow the instructions below to create each MMM Duet System controller.
<table>
<tr valign="top">
<td width="40%">

</td>
<td width="60%">
<ul>
<li>(A) Cut handle to a length of no more than 85mm. Ensure no burs are present to ensure a smooth rotation. </li>
<li>(B) Apply a small amount of epoxy into the hole and quickly set the rod in place. </li>
<li>Let dry before continuing. </li>
<li>(C) Insert the nylon lock nut into the knob such that the hexagon side is towards the circular hole.  </li>
<li>(D) Insert M3x12 screw bolt through handle into knob(C). </li>
</ul>
</td>
</tr>
<tr valign="top">
<td width="40%">


</td>
<td width="60%">
<ul>
<li>Cut two pieces of wire about 80mm in length; strip both ends.</li>
<li>(A) Hook a wire through each eyelet of the button. </li>
<li>(B) Trim a solder seal butt connector so that the solder is placed where the wire loops onto itself and touches the eyelet.</li> 
<li>Use heat gun to seal butt connector </li>
<li>Repeat for other wire</li>
<li>(C) At the end of the wire, opposite of the button, connect, place a spade connector (female), crimp close and use the heat gun to seal. Optional, you can wire to the protoboard directly, but the wire would need to be cut if any changes would occur in the future. </li>
<li>Repeat for other wire </li>
<li>Remove washer if it is already on the button.</li>
<li>(D) Feed wires through the hole in the base and then through the washer</li>
<li>(E) Tighten washer</li>
</ul>
</td>
</tr>
<tr valign="top">
<td width="40%">


</td>
<td width="60%">
<ul>
<li>    Align rotary encoder base with the holes in the music box base. </li>
<li>    (A) Insert 2-M2.6x8 screws in two holes that fit snuggly.  </li>
<li>    (B) Align Handle Base (cylinder shape) with the holes in the base. </li> 
<li>    Insert 4-M3x8 screw bolts in the aligned holes </li>
</ul>
</td>
</tr>
<tr valign="top">
<td width="40%">

</td>
<td width="60%">
<ul>
<li>    Adjust the resolution of the encoder to the desired amount. Between 48 and 125 pulses per revolution. See the rotary encoder’s manufacturer’s documentation for more details.  </li>
</ul>
</td>
</tr>
<tr valign="top">
<td width="40%">

</td>
<td width="60%">
<ul>
<li>    Push handle as far as possible through the hole at the top of the base. </li>
<li>    (A) Place the coloured sleeve that matches the diameter of the rod approximately 1 mm from the printed model. See https://www.cuidevices.com/product/resource/amt10.pdf for the sleeve sizing guide. </li>
<li>    (B) Place black shaft adapter over the white sleeve. The rod should be difficult to remove at this point. If the sleeve needs to be adjusted remove the shaft adapter and then adjust the sleeve.  </li> 
<li>    (C) Gently clip the encoder into place. The black tabs of the encoder base break easily. </li>
</ul>
</td>
</tr>
<tr valign="top">
<td width="40%">

</td>
<td width="60%">
<ul>
<li>    (A) Connect button spade connectors of the protoboard to those of the ESP32. </li>
<li>    (B) Push LED light snuggly into hole </li>
<li>    (C) Connect battery pack to the ESP32 and place battery in pocket. </li> 
<li>    Seat ESP32 in the headers of the protoboard. </li>
<li>    Place protoboard in slot </li>
<li>    (D) Connect the 5 Position MTA 100 connector to the rotary encoder. </li>
<li>   (Optional) (E) Use hot glue gun to improve stability of protoboard and ease of installation. </li>
</ul>
</td>
</tr>
<tr valign="top">
<td width="40%">

</td>
<td width="60%">
<ul>
<li>Add bottom panel and screw into place with M3x12 bolt screws. </li>
</ul>
</td>
</tr>
<tr valign="top">
<td width="40%">

</td>
<td width="60%">
<ul>
<li>    Enjoy! </li>
</ul>
</td>
</tr>
</table>

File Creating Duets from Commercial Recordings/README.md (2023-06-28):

<h1>Creating Duets from Commercial Recordings</h1>

<h2><u>Overview:</u></h2>
Wav files that can be purchased on either Qobuz or Bandcamp or other places that sell Hi-Res music files (such as flac or wav files. If you choose to purchase flac files you will need to convert them into wav files before source separating them, and can do this in audacity – a free audio editing software that is plenty good enough for everything needed to do here).  

Next, and this may be challenging for some, is to install some form of python3. If needed, please follow an online guide instruction for how to do this. 

Here is a place to download python: https://www.python.org/downloads/ 

Here is a pretty good set of instructions for installing python onto either windows, mac, or linux: https://www.codecademy.com/article/install-python3 

Here is another set of instructions for linux: https://docs.python-guide.org/starting/install3/linux/ 

To use demucs, you will also need to install ffmpeg by typing in python: brew install ffmpeg 

Once you have installed python, please go into python (using terminal or whatever software you will be using) and follow the instructions in the demucs software for musicians at the link here: https://github.com/facebookresearch/demucs#for-musicians 

As the link states, to install this program, in python please type:  

`python3 -m pip install -U demucs `

Then, once demucs is installed, follow the instructions on this page: https://github.com/facebookresearch/demucs/blob/main/docs/mac.md 

As the link states, to run the program, please type:  

`python3 -m demucs -d cpu PATH_TO_AUDIO_FILE_1 `

You will need to replace `PATH_TO_AUDIO_FILE_1` with the name of the path to the audio file in your computer. On a mac you can do this by right-clicking on the file name, and once it has opened the list of commands, press the option key, which will bring up the option for copy ___ as Pathname. Choose this and insert it into the text above instead of `PATH_TO_AUDIO_FILE_1`

## Instructions
Audiofiles of songs can be separated, giving one player the vocals and some of the instruments, the rest of the instruments (and sometimes the other vocals) given to the other player. We have used a number of different methods for ‘source separation’, but the most recent method that we have been following is **Demucs Music Source Separation** (with instructions on how to use this above).  

Once made, the audio files need to be stored in the **MMM_Project\media** folder. Follow the instructions in section x to upload them into the Max patch. 

### **Song Library**

The song library is stored on textfiles outside of the patch and is referred to whenever a player opens the dropdown menu (listed as songlist-alphabetical.txt, songlist-year.txt, and songlist-tempo.txt). Here is an example from songlist-alphabetical.txt:
Screen shot of a the song list

Entries other than the reference number (the first number which is followed by a comma) in this list are separated by spaces, and each line is separated by a semicolon (NB There needs to be an empty line after the final line or max cannot read the final semicolon and the final line is lost). In this file, each line lists its reference number, the audiofile for mbox1 (generally accompaniment), the audiofile for mbox2 (generally the melody), the opensource picture that covers over the screen, the average song tempo, and the year of recording. Other characteristics of each song can be added to this file, the number of characteristics just needs to be matched with the unpack function in the max patch. 

There are currently 3 versions of these textfiles. One that is in alphabetical order, one that is arranged according to year of performance, and one that is arranged according to average tempo of the song. Each of these files need to be adjusted when adding new songs. 

Also, in order to have the dropdown menu match these files, the **p titlebar** subpatch needs to be adjusted to match the order of these textfiles. The example below shows an example message for alphabetical order. 
Screenshot of the p titlebar subpatch

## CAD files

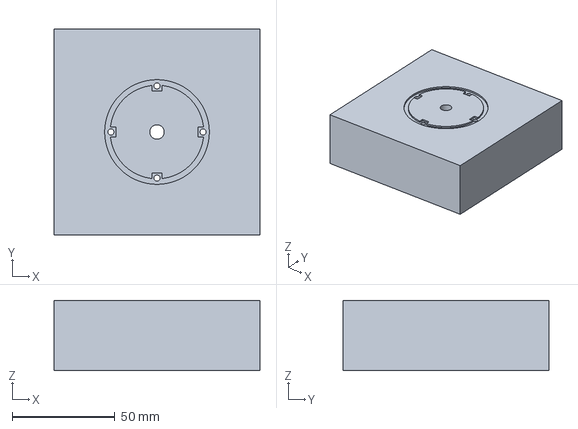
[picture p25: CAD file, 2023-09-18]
MMM_Duet_System_Hardware/Model Files/Base/BaseTop.3mf
100.0 x 100.0 x 34.0 mm

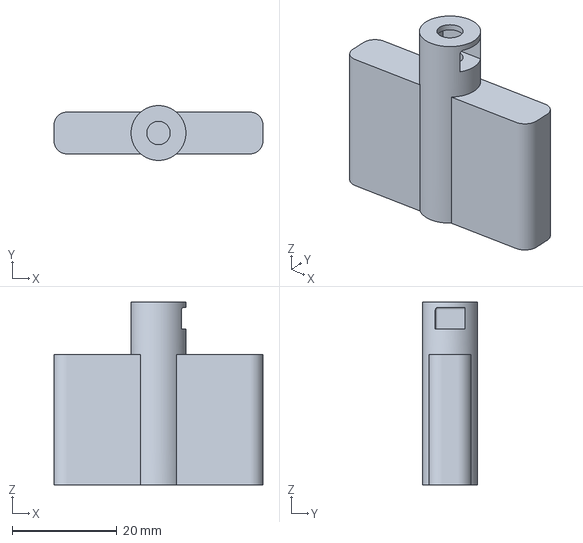
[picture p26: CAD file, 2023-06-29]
MMM_Duet_System_Hardware/Model Files/Handle/Knob.3mf
40.0 x 10.5 x 35.0 mm

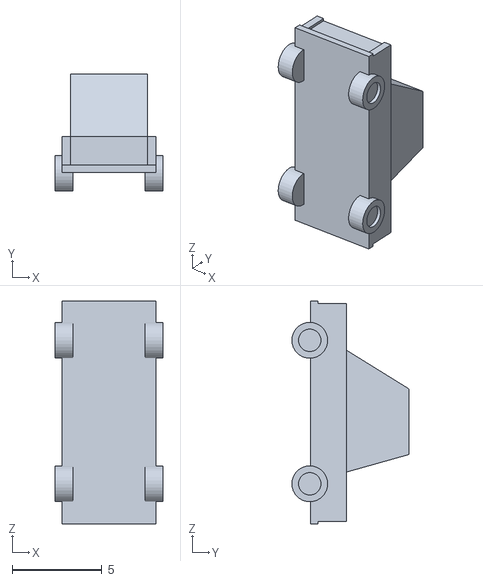
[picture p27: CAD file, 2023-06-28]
MMM_Duet_System_Software/MMM_Project/media/car_one_piece_blue.obj
6.00 x 6.54 x 12.4

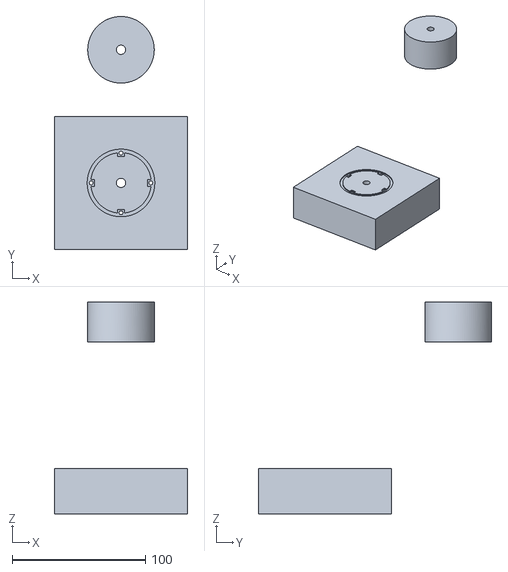
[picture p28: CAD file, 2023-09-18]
MMM_Duet_System_Hardware/Model Files/Base/2022_base_model.stl
100.0 x 175.0 x 158.9

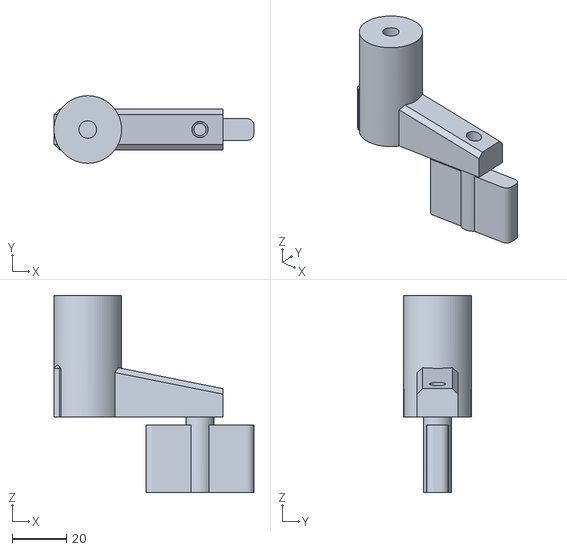
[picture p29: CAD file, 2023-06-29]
MMM_Duet_System_Hardware/Model Files/Handle/Crank50mm_solid.stl
74.0 x 25.0 x 73.0

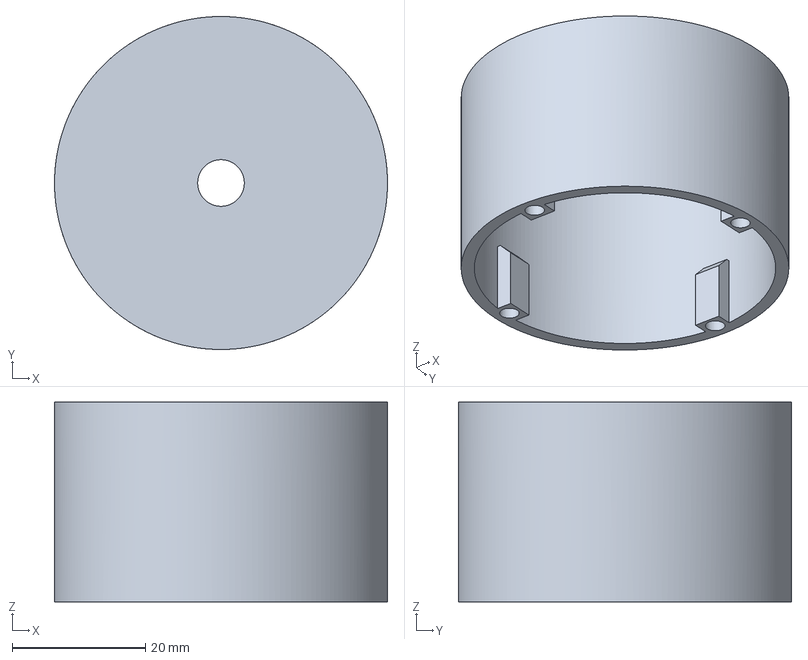
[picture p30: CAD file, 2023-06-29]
MMM_Duet_System_Hardware/Model Files/Base/HandleBase.3mf
50.0 x 50.0 x 30.0 mm

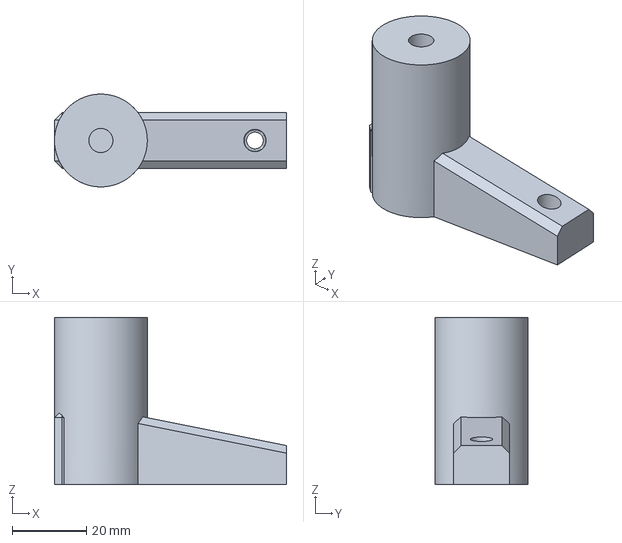
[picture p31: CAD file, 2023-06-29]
MMM_Duet_System_Hardware/Model Files/Handle/SolidHandle.3mf
62.5 x 25.0 x 45.0 mm

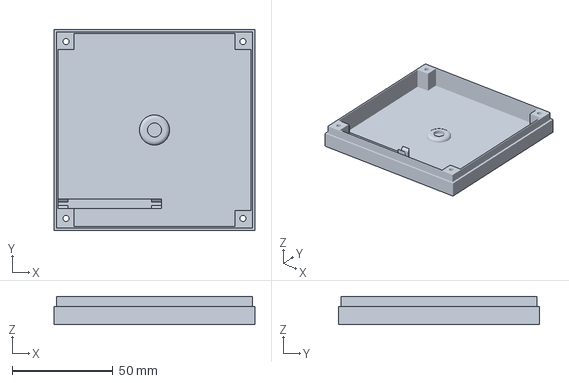
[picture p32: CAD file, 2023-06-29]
MMM_Duet_System_Hardware/Model Files/Base/BaseBottom.3mf
100.0 x 100.0 x 14.0 mm

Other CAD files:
MMM_Duet_System_Software/MMM_Project/media/car_one_piece.obj
MMM_Duet_System_Hardware/Model Files/Base/2022_base_model.f3z
MMM_Duet_System_Hardware/Model Files/Base/BaseBottom.obj
MMM_Duet_System_Hardware/Model Files/Base/BaseBottom.stl
MMM_Duet_System_Hardware/Model Files/Base/BaseTop.obj
MMM_Duet_System_Hardware/Model Files/Base/BaseTop.stl
MMM_Duet_System_Hardware/Model Files/Base/HandleBase.obj
MMM_Duet_System_Hardware/Model Files/Base/HandleBase.stl
MMM_Duet_System_Hardware/Model Files/Handle/Crank50mm_solid.f3d
MMM_Duet_System_Hardware/Model Files/Handle/Knob.obj
MMM_Duet_System_Hardware/Model Files/Handle/Knob.stl
MMM_Duet_System_Hardware/Model Files/Handle/SolidHandle.obj
MMM_Duet_System_Hardware/Model Files/Handle/SolidHandle.stl

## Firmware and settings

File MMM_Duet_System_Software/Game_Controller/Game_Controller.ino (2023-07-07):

#include "driver/rtc_io.h"
#include "BluetoothSerial.h" 
#include <OSCMessage.h>


#define IS 32 // Index Signal
#define AS 15 // A Signal
#define BS 33 // B Signal
#define Light 13 // LED 
#define BatteryVoltage 35 // Battery voltage has to be read from a non-exposed pin A13/35

const uint16_t maxJumpInTime = 5000; 
int stateA;
int stateB;
int previousStateA;

uint16_t val; // The difference between current time from start and last recorded movement
uint16_t prevval; // Previous difference of val
uint16_t wait = 0;       //new
unsigned long currentTimeSinceStart = 0; // Number of milliseconds since program start
unsigned long lastRecordedTime = 0;  
unsigned long timeOfLastRecordedMovement = 0; // Milliseconds from start of last recorded movement

const unsigned long inactionMaxDuration = 150000; //Maximum length of time before entering deep sleep mode (5min)

float currentVoltage;
const float adcReferenceVoltage = 1.1; // Specific to the ESP32 pin, converts anolog voltage to a digital number (1100mV).
const float esp32ReferenceVoltage = 3.3; // ESP32 board specific
const int adcConversion = 4028; // ADC value of the ESP32 is a 12-bit number and this converts it to decimal
const float minimumVoltageAlert = 3.3; // ESP32 disables battery at this level 
bool ledErrorCode[] = {false,false}; // Variable to set the amount of blinking for LED light. Array position: 0 = bluetooth connection established, sufficient battery 
unsigned long ledRecordedTime = 0; // Used for LED flashing, not rotation calculation
unsigned long batteryTestInterval = 60000;
unsigned long ledInterval; //Interval between blinks based on error code
int ledState; //State of LED, High or low

BluetoothSerial ESP_BT; //Object for Bluetooth

void setup(){
  Serial.begin(115200);
  
  
  if(!ESP_BT.begin("MMM_Box_Blue")){ // Bluetooth Name    
    ledErrorCode[0] = false;
  } else {
    // More conditions need to be added for connectivity error code to be considered implemented
    ledErrorCode[0] = true;
  }
  
  pinMode (AS, INPUT); 
  pinMode (BS, INPUT);
  pinMode(Light, OUTPUT); 
 
  previousStateA = digitalRead(AS); // Read the initial state
  Serial.print("Current voltage: "); Serial.println(checkVoltage()); //Get initial voltage of battery and provide errorcode if necessary

  esp_sleep_enable_ext0_wakeup((gpio_num_t)GPIO_NUM_14, 1);  //Sets the 14 pin as the wakeup pin
  
}


/**
 * Returns current voltage of battery and if below threshold update error code. 
 */
float checkVoltage(){
    // Voltage of battery (Needs to be doubled from the value at the pin. You can compare this value to that read from the GND and BAT pins
   currentVoltage = 2* analogRead(BatteryVoltage) * adcReferenceVoltage * esp32ReferenceVoltage / adcConversion ; 
   if (currentVoltage < minimumVoltageAlert){
    ledErrorCode[1] = false;
   } else {
    ledErrorCode[1] = true;
   }
   return currentVoltage; 
 }


/**
 * Modifies ledInterval to reflect the error code
 */
void ledPeriod(){
  if (ledErrorCode[0] == false){
    ledInterval = 500; // If there is no bluetooth connection
  } else if (ledErrorCode[0]  && !ledErrorCode[1]){
    ledInterval = 2500; // If there there is a low battery
  } else { // All other cases
    ledInterval =0;
  }
}

/**
 * Checks if sufficient time has elapsed between last recorded movement and current loop
 * to merit entering sleep mode
 */

void checkSleep(){
   //Enter sleep mode if time between spins is greater than inaction max duration
  if (inactionMaxDuration < (currentTimeSinceStart - timeOfLastRecordedMovement)){
    esp_deep_sleep_start();
    }
}

/**
 * Set LED to blink in accordance with error code
 */
void setLEDState (){
  // If both errorcodes are true i.e. no error
  if (ledErrorCode[0] && ledErrorCode[1]){
      digitalWrite(Light, HIGH);
      ledState = HIGH;
    } else {
      ledPeriod();
      if (currentTimeSinceStart - ledRecordedTime >= ledInterval) {
        if (ledState == LOW) {
          digitalWrite(Light, HIGH);
          ledState = HIGH;
        } else {
          digitalWrite(Light, LOW);
          ledState = LOW;
        }
      }
    }
}

void loop(){
  

  currentTimeSinceStart = millis(); // Get milliseconds from start  
  checkSleep(); // Check inactivity
  
  // Update the battery errorcode periodically based on batteryTestInteval
  if ( batteryTestInterval < (currentTimeSinceStart - ledRecordedTime)){
    checkVoltage();
    Serial.println(currentVoltage = 2* analogRead(BatteryVoltage) * adcReferenceVoltage * esp32ReferenceVoltage / adcConversion);
    ledRecordedTime = currentTimeSinceStart; // Set recorded time
    }
    
  setLEDState(); // Set LED to blink if an error code is present
    
  
  
  
  // Get current state
  stateA = digitalRead(AS); // Get state of pin A
  stateB = digitalRead(BS); // Get state of pin B
     


    // If the pin A is up or down and pin B is the opposite consider it a position. 
    // Pin A has to be in a different state than it was previously to consider that movement has occured. 
  if (stateA != stateB && stateA != previousStateA)
    {        
        val = currentTimeSinceStart - timeOfLastRecordedMovement;
        if (val != prevval && val != 0 && val < 40) {       //No need to repeat sending out same info as before. & Pracitcally physically impossible to spin slower than once every 30 msec.
          OSCMessage oscMsg("/a"); // The 30 MSEC ABOVE MAY NEED TO BE CHANGED FOR A SLOWER MUSICBOX. CHECK SLOWEST SPINNING SPEED AND ADJUST TO THAT.
          oscMsg.add(val);  
          oscMsg.send(ESP_BT); // send the bytes
          oscMsg.empty(); // free space occupied by message
        }

        timeOfLastRecordedMovement = currentTimeSinceStart;
        previousStateA = stateA;
        wait = 0;
        prevval = val;
  } 
  else if (currentTimeSinceStart - lastRecordedTime >= 320) {
      if (wait == 0) {                //if wait time is greater than 320 msec.
        wait = 1;
        OSCMessage oscMsg("/D");       //sends out message "D" after 320 msec.
        oscMsg.send(ESP_BT);          // send the bytes
        oscMsg.empty(); 
      }
      else if (wait == 1) {
        wait = 2;
        OSCMessage oscMsg("/E");               //sends out message "E" after 640 msec.
        oscMsg.send(ESP_BT); 
        oscMsg.empty(); 
      }
      else if (wait ==2) {                  // if greater than 960 msec, reset and send out value 
        OSCMessage oscMsg("/F");           //if still connected but no motion, then sends out message "F" every 320 msec.
        oscMsg.send(ESP_BT);              // send the bytes
        oscMsg.empty();                  // Max seems to stop listening after a while so this won't work as a way to measure if bluetooth still connected ... 
      }

      lastRecordedTime = currentTimeSinceStart;
    }

 }

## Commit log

2023-06-26 Added landing page README
2023-06-26 Added assembly images to hardware section
2023-06-28 Initial commit of Max files, some editing changes including relettering
    [car_one_piece.obj, car_one_piece_blue.obj]
2023-06-28 Moved Max project into Software Directory
    [car_one_piece.obj, car_one_piece_blue.obj]
2023-06-29 Minor tweaks to readme, including important files. Added Model Files
    [2022_base_model.f3z, 2022_base_model.stl, BaseBottom.3mf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]
2023-07-07 Added Arduino Game Controller Script
2023-09-13 Added soldering instructions
2023-09-18 Added tab to support USB connection
    [2022_base_model.f3z, 2022_base_model.stl, BaseTop.3mf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]
